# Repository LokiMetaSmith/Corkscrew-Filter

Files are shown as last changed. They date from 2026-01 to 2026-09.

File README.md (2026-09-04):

# OpenAuto-CFD: Universal Configuration-Driven CFD Optimizer

OpenAuto-CFD is a powerful "Software-Defined Engineering" framework designed for the autonomous generation, simulation, and optimization of 3D-printable fluid dynamics components. It creates a seamless loop integrating parametric Computer-Aided Design (OpenSCAD), Computational Fluid Dynamics (OpenFOAM), and Generative Artificial Intelligence (LLM) to perform automated searches of high-dimensional design spaces.

By leveraging a universal Configuration-Driven Architecture (via YAML Problem Definition files), OpenAuto-CFD is not tied to a single geometry. Instead, it allows users to specify parameter ranges, physics constraints, and optimization goals, enabling an AI "Virtual Engineer" to iteratively design, simulate, and refine models toward an optimal solution.

## Key Features

*   **Universal Configuration-Driven Architecture**: Define any parametric optimization problem via a single YAML file, decoupled from hardcoded logic.
*   **KiCad 10 Action Plugin (OpenAuto EM Live Bridge)**: Official KiCad 10/9/8/7 `pcbnew.ActionPlugin` creating an instant electromagnetic feedback loop (<100 ms). Modifying traces on the PCB canvas and saving (`Ctrl+S`) automatically recalculates controlled impedance ($Z_0, Z_{diff}$), S-parameters ($S_{11}, S_{21}$), and regenerates HyperLynx (`.hyp`) and openEMS FDTD models.
*   **EDA, Chip Design & RF Transmission Line Synthesis**: Wheeler and Hammerstad conformal mapping for microstrip and coupled differential pairs with finite copper thickness, frequency-dependent skin depth attenuation, and automated `.kicad_pcb` layout generation.
*   **Multi-Physics Surrogate & Model Fusion**: Universal RBF surrogate supporting coupled CFD (OpenFOAM), FEA structural stress (CalculiX), and EM (openEMS) metrics with 3D spatial vector fields and binary GPU buffer export.
*   **Real-Time Interactive WebGL Viewer (Atlas-Style HUD)**: Modern Three.js dark-mode HUD with 60 FPS real-time parameter scrub, swirling particle ribbons, FEA stress heatmaps, AI inverse design controls, and KiCad EM sync toast alerts.
*   **Multi-Fidelity Mesh Pyramid**: Kennedy & O'Hagan Co-Kriging model ($y_H = \rho y_L + \delta(x)$) with dynamic mesh resolution switching and a Two-Stage Active Screening Filter delivering a $2.9\times$ compute speedup.
*   **Physics-Informed Conservation Regularizer (PINN)**: Discrete Exterior Calculus Helmholtz-Hodge solenoidal projector $(D D^T) \boldsymbol{\lambda} = D \mathbf{u}$ enforcing incompressibility continuity ($\nabla \cdot \mathbf{u} = 0$) with $100\%$ divergence elimination in $<25\text{ ms}$, plus Cauchy stress divergence equilibrium ($\nabla \cdot \boldsymbol{\sigma} \approx \mathbf{0}$).
*   **LLM Tool-Calling CAD & EDA Reasoning Agents**: Exposes standard OpenAPI / JSON Schema function-calling tools (`predict_surrogate`, `run_inverse_design`, `optimize_trace_impedance`, `evaluate_rf_transmission`, `generate_kicad_pcb`, `generate_scad_code`) for autonomous multi-turn engineering reasoning.
*   **Exact Differentiable Gradients**: Analytic exact derivatives ($\approx 10^{-10}$ error vs finite differences) and multi-start L-BFGS-B inverse design converging in $<10\text{ ms}$.
*   **Model Context Protocol (MCP) Interface**: Exposes a standard MCP server for external LLMs (e.g. Claude Desktop, Cursor) to directly query harness state, list configs, run parametric CAD & physics simulations, and execute Schema surrogate steps.

---

## Case Study: Parametric Corkscrew Filter

To demonstrate the capabilities of OpenAuto-CFD, this repository includes a comprehensive system validation study: the **Parametric Corkscrew Filter**.

This is a 3D-printable inertial filter designed for separating particles from a fluid stream—ideal for challenging environments like mitigating abrasive lunar regolith.

### Theory of Operation

The corkscrew filter combines advanced fluid dynamics principles with the AI-driven engineering of OpenAuto-CFD.
See the [TECHNICAL_REPORT.md](./TECHNICAL_REPORT.md) for a detailed explanation of the physics and validation results.

#### Physics of Inertial Separation

The core mechanism of the corkscrew filter is **inertial separation**. As fluid traverses the helical channel, it is subjected to rapid changes in direction, inducing specific forces:

1.  **Centrifugal Force ($$F_c = m \frac{v^2}{r}$$)**: The helical geometry acts as a continuous centrifuge. Heavier particles possess greater inertia and are flung toward the outer wall of the channel.
2.  **Dean Vortices**: In curved pipes, the velocity differential creates secondary flows known as Dean Vortices that sweep the cross-section and transport particles toward trapping zones.
3.  **"Clog-Free" Trapping**: Unlike barrier filters (e.g., HEPA), this design uses "stepped traps" to eject particles *out* of the main flow stream into a quiescent collection bin. The filter maintains constant flow conductance until the bin is physically full.

## Getting Started

### 1. Install Dependencies

*   **Node.js**: Run `npm install` in the root directory to install geometry generation tools (`openscad-wasm`).
*   **Python**:
    It is highly recommended to use a virtual environment. The `start_optimization.sh` script handles this automatically (creating `.venv`). If installing manually:
    ```bash
    python3 -m venv .venv
    source .venv/bin/activate  # On Windows, use `.venv\Scripts\activate`
    pip install -r optimizer/requirements.txt
    ```

### 2. Generating the 3D Models (OpenSCAD)

The 3D models for the filter are generated using OpenSCAD.
1.  **Open the Main File**: Open the `corkscrew.scad` file in OpenSCAD (or use the CLI tools provided).
2.  **Configure Parameters**: Adjust the parameters in `config.scad` or the `parameters/` directory.
3.  **Render and Export**: Render the model (F6) and export it as an STL file for 3D printing.

#### Key Parameters (`corkscrew.scad`)
*   `filter_height_mm`: The height of the filter.
*   `number_of_complete_revolutions`: The number of turns in the corkscrew channels.
*   `screw_OD_mm`, `screw_ID_mm`: The outer and inner diameters of the corkscrew channels.
*   `num_screws`: The number of parallel corkscrew channels.
*   `num_bins`: The number of collection bins.

### 3. Automated Optimization & Parameters

The `optimizer/` directory contains tools to automate the design-simulation-analysis loop using the OpenAuto-CFD framework.
*   See [optimizer/README.md](./optimizer/README.md) for details on the AI-driven optimization workflow and MCP server usage.
*   See [parameters/README.md](./parameters/README.md) for information on parameter configuration files.

> **Pro Tip:** When running the optimizer `main.py`, you can parallelize the meshing and CFD solver by using the `--cpus X` flag (where X is the number of cores). This makes OpenFOAM execute much faster!

### 4. Running the MCP Server

OpenAuto-CFD includes a Model Context Protocol (MCP) interface allowing AI assistants (Claude Desktop, Cursor, etc.) to drive evaluations and inspect harness state:

```bash
PYTHONPATH=optimizer python3 -m optimizer.mcp_server
```

To configure with Claude Desktop (`claude_desktop_config.json`):
```json
{
  "mcpServers": {
    "openauto-cfd": {
      "command": "python3",
      "args": ["-m", "optimizer.mcp_server"],
      "env": {
        "PYTHONPATH": "/path/to/OpenAuto-CFD/optimizer"
      }
    }
  }
}
```

### 4. CFD Simulation (Advanced)

This project includes a base case setup for running a CFD simulation using OpenFOAM. For detailed instructions on how to set up and run the simulation, please see the [README.md in the `corkscrewFilter` directory](./corkscrewFilter/README.md).

### 5. Launching the Real-Time Interactive WebGL Viewer (Atlas HUD)

To launch the real-time browser-based Atlas 3D simulation viewer:
```bash
python run_viewer.py
```
This starts the local threaded REST server on port 8080 and opens the WebGL interface. The viewer features:
* **60 FPS Parameter Scrub**: Scrub geometric sliders with instant surrogate response.
* **Particle Streamline Ribbons**: Dynamic swirling flow ribbons colored by velocity magnitude.
* **FEA Stress Heatmaps**: Visualizes von Mises stress distributions across the geometry.
* **AI Inverse Design**: One-click multi-start gradient descent button to find optimal parameters.

### 6. Running the Autonomous CAD Reasoning Agent (Kimi K3 / Gemini / OpenAI)

You can launch an autonomous engineering session where the agent executes multi-turn tool calling (predicting surrogate surfaces, verifying physical conservation, and writing valid `.scad` files):
```bash
PYTHONPATH=optimizer python3 -c "
from cad_agent_tools import CADReasoningAgent
agent = CADReasoningAgent()
res = agent.run_goal('Optimize lunar regolith corkscrew filter for >95% efficiency and low pressure drop')
print(res['summary'])
"
```

### 7. KiCad 10 Action Plugin: OpenAuto EM Live Bridge

The repository includes a native **KiCad 10.0** (and 9/8/7) Action Plugin located in [`kicad_plugin/`](./kicad_plugin/). It connects KiCad PCB Editor (`pcbnew`) directly to the simulation engine, providing a live on-save electromagnetic feedback loop.

#### 1-Command Installation
```powershell
# Windows PowerShell
.\install_kicad_plugin.ps1
```
```bash
# Linux / macOS
./install_kicad_plugin.sh
```
*Or directly via Python:*
```bash
python kicad_plugin/install_plugin.py
```

#### How to Use in KiCad 10:
1. Start the simulation viewer: `python run_viewer.py`
2. Open KiCad 10 PCB Editor (`pcbnew`).
3. Click **Tools** $\rightarrow$ **External Plugins** $\rightarrow$ **Refresh Plugins**.
4. Click the **OpenAuto EM Live Bridge** toolbar button.
5. Edit trace widths or differential pairs and hit **Ctrl+S**: the WebGL HUD instantly updates with live $Z_0$ and $S_{11}$ telemetry (<100 ms).

*See the dedicated [kicad_plugin/README.md](./kicad_plugin/README.md) for architecture, Wheeler conformal equations, and openEMS FDTD script generation.*

---

## Testing & Verification

To run the automated verification suites covering all multi-physics, EDA, distributed swarm, and KiCad plugin modules:

```bash
# Set PYTHONPATH to include optimizer, viewer, and kicad_plugin directories
export PYTHONPATH="optimizer:viewer:kicad_plugin"  # On Windows PowerShell: $env:PYTHONPATH="optimizer;viewer;kicad_plugin"

# 1. KiCad 10 Action Plugin & Real-Time On-Save EM Recalculation Loop
python verify_kicad_plugin.py

# 2. EDA, Chip Design & RF Transmission Lines (Wheeler Conformal Mapping & S-Params)
python verify_eda_chip_design.py

# 3. Live WebGL Viewer Upgrades (HUD Physics Telemetry & AI Agent Chat Drawer)
python verify_viewer_upgrades.py

# 4. Multi-Algorithm Benchmark & Pareto Front Analysis (Random vs L-BFGS-B vs PINN vs CAD Agent)
python verify_benchmark_suite.py

# 5. Distributed Worker Swarm & Git-Based Job Queue (Atomic Claims & Heartbeat)
python verify_distributed_swarm.py

# 6. Physics-Informed Conservation Regularizer (PINN & Discrete Exterior Calculus)
python verify_pinn_conservation.py

# 7. Autonomous CAD Agent Tool-Calling Suite
python verify_cad_agent.py

# 8. Multi-Physics Surrogate Fusion & Binary GPU Buffer IO
python verify_cfd_fea_fusion.py

# 9. Multi-Fidelity Mesh Pyramid & Two-Stage Active Screening
python verify_multifidelity.py
```

## Assembly

For a complete list of materials required and assembly instructions for the Corkscrew Filter validation study, please see the [Bill of Materials (BOM.md)](./BOM.md).

## Future Work

For a list of planned enhancements and roadmap items, please see the [TODO list (TODO.md)](./TODO.md).

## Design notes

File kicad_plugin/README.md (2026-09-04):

# OpenAuto EM Live Bridge — KiCad Action Plugin

**OpenAuto EM Live Bridge** is an official KiCad Action Plugin (`pcbnew.ActionPlugin`) compatible with **KiCad 10.0**, 9.0, 8.0, and 7.0. It bridges KiCad PCB Editor directly to real-time electromagnetic (EM) and signal/power integrity (SI/PI) simulation.

Whenever you modify and save a board in KiCad (`Ctrl+S`), the plugin automatically re-evaluates high-speed trace physics, exports simulation handoff files (Siemens HyperLynx `.hyp`, openEMS 3D FDTD `.py`, and OpenSCAD `.scad`), and broadcasts live metrics to an interactive WebGL HUD with **<100 ms feedback latency**.

---

## Key Capabilities

* **Zero-Lag Interactive Editing Loop**: Modifying microstrip trace width ($w$) or differential pair spacing ($s$) and saving in KiCad instantly updates impedance gauges and S-parameter plots in your browser.
* **Controlled Impedance Physics ($<5\text{ ms}$)**:
  * **Single-Ended Microstrip**: Wheeler and Hammerstad conformal mapping with finite copper thickness ($t$) corrections.
  * **Coupled Differential Pairs**: Odd/even mode impedances ($Z_{odd}, Z_{even}$) and differential impedance ($Z_{diff} = 2 Z_{odd}$) with edge-to-edge spacing ($s$).
  * **Frequency-Dependent Loss**: Skin depth attenuation ($\delta = \sqrt{1/\pi f \mu \sigma}$), conductor loss ($\alpha_c$), dielectric loss ($\alpha_d$), and return loss ($S_{11}$).
* **Multi-Solver Simulation Export**:
  * **Siemens HyperLynx (`.hyp`)**: Native high-end EDA intermediate format for HyperLynx, Ansys HFSS, and Keysight ADS.
  * **openEMS FDTD (`.py`)**: Ready-to-run 3D finite-difference time-domain simulation script with excitation ports and absorbing boundary conditions (PML).
  * **OpenSCAD Solid Geometry (`.scad`)**: Full 3D solid model of dielectric substrate and etched copper traces.
* **Decoupled Pure-Python S-Expression Parser**: Tokenizes `.kicad_pcb` files with zero external C++ dependencies, extracting board outlines (`Edge.Cuts`), layer dielectric stackups, and net geometries.
* **KiCad 10.0 Native Compatibility**: Built-in `wx.GetApp()` GUI guards preventing wxWidgets C++ assertion faults (`assert "PgmOrNull()"`), bundled physics engine running on KiCad 10's internal Python 3.11 + NumPy runtime.

---

## Directory Structure

```
kicad_plugin/
├── __init__.py                # KiCad package entry point & GUI registration
├── action_openauto_em.py      # pcbnew.ActionPlugin implementation & toolbar button
├── em_live_watcher.py         # On-save file watcher daemon (<50ms response)
├── kicad_parser.py            # Pure-Python .kicad_pcb S-expression parser
├── eda_rf_driver.py           # Wheeler/Hammerstad & S-parameter physics engine
├── metadata.json              # Official KiCad PCM manifest (v1.0.0 for KiCad 10.0)
├── icon.png                   # 26x26 toolbar icon with RF microstrip wave symbol
├── install_plugin.py          # Cross-platform CLI auto-installer script
└── README.md                  # This documentation
```

---

## Installation

### Method 1: Automatic Installer (Recommended)

From the project root directory, run the Python auto-installer:

```bash
# On Windows (PowerShell)
python kicad_plugin/install_plugin.py

# Or with live development symlink (no file copying)
python kicad_plugin/install_plugin.py --symlink
```

You can also use the convenience scripts from the root:
```powershell
# Windows PowerShell
.\install_kicad_plugin.ps1
```
```bash
# Linux / macOS
./install_kicad_plugin.sh
```

The installer automatically searches standard KiCad user directories in order of priority:
1. **Windows**: `%APPDATA%\kicad\10.0\scripting\plugins\openauto_em_live`
   *(fallbacks: `9.0`, `8.0`, `7.0`, `6.0`)*
2. **Linux**: `~/.local/share/kicad/10.0/scripting/plugins/openauto_em_live`
3. **macOS**: `~/Library/Preferences/kicad/10.0/scripting/plugins/openauto_em_live`

#### Custom Installation Directory
To install into a specific path:
```bash
python kicad_plugin/install_plugin.py --dir "C:\custom\path\to\kicad\plugins"
```

---

### Method 2: Manual Installation

Copy the entire `kicad_plugin/` folder into your KiCad user scripting directory and rename it to `openauto_em_live`:

* **Windows**:
  ```powershell
  New-Item -ItemType Directory -Force "$env:APPDATA\kicad\10.0\scripting\plugins"
  Copy-Item -Recurse -Force "kicad_plugin" "$env:APPDATA\kicad\10.0\scripting\plugins\openauto_em_live"
  ```
* **Linux**:
  ```bash
  mkdir -p ~/.local/share/kicad/10.0/scripting/plugins
  cp -r kicad_plugin ~/.local/share/kicad/10.0/scripting/plugins/openauto_em_live
  ```
* **macOS**:
  ```bash
  mkdir -p ~/Library/Preferences/kicad/10.0/scripting/plugins
  cp -r kicad_plugin ~/Library/Preferences/kicad/10.0/scripting/plugins/openauto_em_live
  ```

---

### Method 3: KiCad Plugin and Content Manager (PCM)

The plugin includes an official `metadata.json` compliant with KiCad's PCM schema. To package as a ZIP for manual PCM installation:

```bash
cd kicad_plugin
zip -r ../openauto_em_live_pcm.zip . -x "__pycache__/*"
```
In KiCad main window:
1. Open **Plugin and Content Manager** (PCM).
2. Click **Install from File...**
3. Select `openauto_em_live_pcm.zip` and click **Apply Changes**.

---

## Step-by-Step Usage Guide

### 1. Launch the Simulation Server
Before or after opening KiCad, start the local simulation server from the repository root:
```bash
python run_viewer.py
```
This serves the WebGL HUD and REST synchronization endpoints at `http://127.0.0.1:8080`.

### 2. Activate the Plugin in KiCad
1. Open **KiCad 10 PCB Editor** (`pcbnew`).
2. If KiCad was already running, reload plugins via:
   **Tools** $\rightarrow$ **External Plugins** $\rightarrow$ **Refresh Plugins**.
3. A new toolbar button **OpenAuto EM Live Bridge** will appear on your top toolbar:
   Icon
4. Click the toolbar button. KiCad will:
   * Detect the currently open `.kicad_pcb` board file.
   * Start the background `EMLiveSyncDaemon` watching file modification timestamps.
   * Automatically launch your default browser to `http://127.0.0.1:8080?kicad_live=1`.
   * Display the live status pill badge in the WebGL HUD: `KiCad EM Sync: ACTIVE`.

### 3. Edit Traces with Instant Real-Time Feedback
* Select a high-speed RF trace or differential pair in KiCad.
* Adjust trace width (e.g. change $w = 3.0\text{ mm}$ to $w = 1.5\text{ mm}$) or change differential pair pitch.
* Press **Ctrl+S** to save the layout.
* Within **<100 ms**:
  * The WebGL HUD shows a slide-in toast notification:
    > **KiCad EM Sync**: `Board saved! Microstrip Z0 = 72.16 Ω | S11 = -14.83 dB`
  * The characteristic impedance meters and return loss dials update immediately.
  * Fresh simulation bridge files (`artifacts/*_live.hyp`, `artifacts/*_openems.py`) are generated in the background.

---

## REST API Integration

The simulation server (`viewer/server.py`) provides two dedicated endpoints for KiCad synchronization:

| Endpoint | Method | Payload | Description |
| :--- | :---: | :--- | :--- |
| `/api/kicad_sync` | `POST` | `{"pcb_file": str, "em_metrics": dict, "artifacts": dict}` | Ingests live board geometry and RF metrics from `EMLiveSyncDaemon`. |
| `/api/kicad_status` | `GET` | *None* | Returns `{"connected": bool, "board_file": str, "em_metrics": dict}` for WebGL HUD polling. |

---

## Verification & Testing

To run the automated verification suite covering ActionPlugin registration, S-expression parsing, live file watching, and REST synchronization:

```bash
# Run standalone test suite
python verify_kicad_plugin.py
```

### Verified Test Matrix:
* **Test 1: ActionPlugin & PCM Manifest**: Validates PCM schema versioning (`kicad_version: 10.0`), button hooks, and PNG icon asset.
* **Test 2: S-Expression Parser**: Parses stackup parameters ($h, \epsilon_r, t$) and detects differential pair traces (`RF_IN_POS` / `RF_IN_NEG`).
* **Test 3: On-Save Watcher & EM Engine**: Modifies board file from $w=3.043\text{ mm}$ ($Z_0=50.0\,\Omega$) to $w=1.5\text{ mm}$ ($Z_0=72.16\,\Omega$), detecting and recalculating in $<100\text{ ms}$.
* **Test 4: Real-Time Server Sync**: Verifies `/api/kicad_sync` and `/api/kicad_status` state transitions and WebGL telemetry formatting.
* **Test 5: Auto-Installer Discovery**: Verifies resolution of KiCad 10.0, 9.0, 8.0, and 7.0 application paths.

All tests execute with **100% pass rate** in both standard Python virtual environments and KiCad 10's native Python runtime.

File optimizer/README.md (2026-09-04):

# AI-Driven Design Optimization

This directory contains a suite of tools to automate the design optimization of the Corkscrew Filter filter using Generative AI. The system iterates through design parameters, generates 3D geometry, runs CFD simulations to evaluate performance, and uses a Large Language Model (LLM) to suggest improvements.

## Overview

The optimization loop consists of the following steps:
1.  **Parameter Selection**: The system starts with an initial set of parameters or takes suggestions from the LLM.
2.  **Geometry Generation**: `scad_driver.py` uses OpenSCAD to generate an STL file from the parameters.
3.  **CFD Simulation**: `foam_driver.py` prepares and runs an OpenFOAM simulation on the generated geometry. It calculates metrics like pressure drop and residuals.
4.  **Analysis & Suggestion**: `llm_agent.py` sends the simulation results to the Gemini LLM, which analyzes the data and proposes new parameters to test.
5.  **Iteration**: The process repeats for a specified number of iterations.

## How the AI Agent Works

The `LLMAgent` (using Google Gemini) is designed to function as an autonomous engineer. Instead of treating the optimization as a black-box numerical search (like Genetic Algorithms), it reasons through the problem using physics and engineering constraints.

### Inputs
The Agent receives a rich context for every iteration:
*   **Design History**: A JSON log of all previous runs, including parameters used and the resulting metrics.
*   **Simulation Metrics**: Key performance indicators from OpenFOAM, such as **Pressure Drop** (energy cost) and **Particle Residuals** (simulation convergence).
*   **Visual Feedback**: 3D renderings (screenshots) of the generated STL. This allows the model to "see" geometrical errors (e.g., walls that are too thin, disconnected helices) that purely numerical data would miss.
*   **Physics Constraints**: A system prompt that explicitly defines the governing equations (e.g., Centrifugal Force $$F = mv^2/r$$) and design goals.

### Chain-of-Thought Reasoning
The agent is instructed to output its response in a structured JSON format that includes a `reasoning` field. It must:
1.  **Analyze Trends**: Look at the history (e.g., "Increasing pitch last time reduced pressure drop but hurt efficiency").
2.  **Apply Physics**: Relate the trends to theory (e.g., "To recover efficiency without increasing pressure, we should increase the helix radius to boost centrifugal force while keeping the pitch constant").
3.  **Propose Parameters**: Only after this reasoning step does it generate the numerical parameters for the next run.

## Prerequisites

To run the optimization script, you need the following installed and configured:

*   **Python 3.x**: With the required packages installed (`pip install -r requirements.txt` if available, or install `google-generativeai`).
*   **OpenSCAD**: Available in your system PATH.
*   **OpenFOAM**: Installed and sourced (e.g., `simpleFoam`, `blockMesh`, `snappyHexMesh` should be executable).
*   **Google Gemini API Key**: An API key for Google's Generative AI. Set this as an environment variable: `export GEMINI_API_KEY="your_api_key"`.

## Usage

Run the main optimization script from the root of the repository or the `optimizer` directory (adjust paths accordingly):

```bash
python optimizer/main.py --iterations 5 --scad-file corkscrew.scad --case-dir corkscrewFilter
```

### Arguments

*   `--iterations`: Number of optimization cycles to run (default: 5).
*   `--scad-file`: Path to the OpenSCAD model file. **Note:** The script defaults to `corkscrew filter.scad`, but you should typically use `corkscrew.scad` (or your specific model file).
*   `--case-dir`: Path to the OpenFOAM case directory (default: `corkscrewFilter`).
*   `--output-stl`: Name of the generated STL file (default: `corkscrew_fluid.stl`).
*   `--dry-run`: Use this flag to simulate the process without running actual OpenSCAD or OpenFOAM commands (useful for testing the logic).
*   `--cpus`: Set the number of CPUs (cores) to use for parallel meshing and solving in OpenFOAM (default: 1). Use this flag to speed up OpenFOAM processing significantly on multi-core machines.

## File Descriptions

*   **`main.py`**: The central controller script that manages the optimization loop.
*   **`cad_agent_tools.py`**: Standard OpenAPI / JSON Schema tool definitions (`predict_surrogate`, `run_inverse_design`, `check_physics_conservation`, `dispatch_simulation`, `check_simulation_status`, `generate_scad_code`) and `CADReasoningAgent` autonomous multi-turn engineering loop.
*   **`llm_agent.py`**: Multi-provider LLM interface (Google Gemini, OpenAI / Kimi K3, local Ollama) with factory integration for the CAD agent.
*   **`surrogate_multiphysics.py`**: Universal RBF surrogate supporting coupled CFD, FEA, EM, and joint metrics and full 3D spatial field predictions.
*   **`cfd_fea_field_io.py`**: OpenFOAM and CalculiX field parser and high-performance binary GPU buffer (`.bin`) exporter for real-time 3D streaming.
*   **`surrogate_gradients.py`**: Analytic exact RBF derivatives ($\approx 10^{-10}$ error vs finite differences) and `DifferentiableInverseDesigner` multi-start L-BFGS-B optimizer.
*   **`surrogate_multifidelity.py`**: Kennedy & O'Hagan Co-Kriging model ($y_H = \rho y_L + \delta(x)$) with joint epistemic uncertainty.
*   **`multifidelity_driver.py`**: Dynamic mesh resolution controller (4.8mm coarse vs 1.5mm fine).
*   **`model_fusion_multifidelity.py`**: Two-Stage Active Screening Filter that prunes sub-par geometries during coarse runs ($2.9\times$ speedup).
*   **`pinn_conservation.py`**: Physics-Informed Conservation Regularizer implementing Discrete Exterior Calculus Helmholtz-Hodge solenoidal projection ($(D D^T) \boldsymbol{\lambda} = D \mathbf{u}$), fluid vorticity, and structural static equilibrium ($\nabla \cdot \boldsymbol{\sigma} \approx \mathbf{0}$).
*   **`async_solver_queue.py`**: Asynchronous non-blocking worker pool and job dispatcher for OpenFOAM and CalculiX background solves.
*   **`rl_policy_agent.py`**: Contextual policy gradient reinforcement learning actor for continuous geometric parameter morphing.
*   **`foam_driver.py`**: Handles OpenFOAM case preparation, meshing, solving, and results extraction.
*   **`fea_driver.py`**: Handles CalculiX structural FEA case setup, boundary conditions, and stress tensor evaluation.
*   **`scad_driver.py`**: Wraps OpenSCAD command-line tools to generate STL files from parameter sets.
*   **`data_store.py`**: Manages the persistent storage of optimization results in `optimization_log.jsonl`.
*   **`constraints.py`**: Central definitions for optimization goals and parameter constraints.
*   **`parameter_validator.py`**: Geometric manifold and singularity validator for CAD parameters.
*   **`mcp_server.py`**: Model Context Protocol (MCP) server providing standard stdio tool execution for external LLMs.

## Model Context Protocol (MCP) Server

The MCP server (`optimizer/mcp_server.py`) exposes high-level tools for external LLM agents to direct the harness:

### Exposed MCP Capabilities

#### Tools (`@mcp.tool`)
1. `list_available_configs`: Discovers all YAML problem definition files in the codebase.
2. `run_simulation_tool`: Triggers OpenSCAD geometry generation and CFD/EM/FEA simulations with specific parameters.
3. `get_harness_status`: Queries optimization history, total runs, and top-performing parameter sets.
4. `get_run_details`: Fetches full details, metrics, and artifact paths for a specific run ID.
5. `get_schema_state`: Retrieves the current Schema surrogate state, timeline discrepancy log, and notes.
6. `run_schema_step`: Executes an iteration of the physicist-style Schema surrogate planning loop.
7. `validate_parameters_tool`: Performs pre-flight constraint validation on proposed CAD parameter sets.
8. `suggest_parameters_tool`: Invokes the internal AI agent / Optuna optimizer to propose candidate parameters.
9. `generate_training_dataset_tool`: Formats historical simulation logs into OpenAI, Alpaca, or DPO fine-tuning datasets with synthesized CoT reasoning.

#### Resources (`@mcp.resource`)
* `config://corkscrew_config.yaml`: Read standard Corkscrew Filter CFD configuration YAML.
* `log://latest`: Read the latest simulation run record from the optimization log.
* `schema://notes`: Read physicist notes (`notes.md`) recorded during Schema surrogate iterations.

#### Prompts (`@mcp.prompt`)
* `analyze_simulation_results`: Generates structured prompt guiding an LLM on analyzing simulation metrics and recommending parameter mutations.
* `schema_surrogate_reasoning`: Generates prompt template for mechanism discovery and surrogate updates when state discrepancy occurs.

### Launching the MCP Server
```bash
PYTHONPATH=optimizer python3 -m optimizer.mcp_server
```

## Data Storage

Results are stored in `optimization_log.jsonl`, a JSON Lines file where each line is a self-contained JSON object representing a single optimization run. This format allows for efficient append-only logging and easier merging of results from distributed runs.

Each entry contains:
*   `id`: Unique UUID for the run.
*   `timestamp`: UTC timestamp.
*   `status`: Status of the run (e.g., "completed").
*   `git_commit`: The git commit hash at the time of execution.
*   `parameters`: The input parameters used.
*   `metrics`: The output metrics from the simulation.

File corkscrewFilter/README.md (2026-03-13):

# OpenFOAM Case for Corkscrew Filter

This directory contains the necessary files to run a basic CFD simulation of the corkscrew filter using OpenFOAM. This guide summarizes the workflow.

## Step 1: Generate and Place Geometry

1.  Open the `corkscrew filter.scad` file.
2.  Set the `GENERATE_CFD_VOLUME` parameter to `true`.
3.  Render the model (F6) and export the resulting geometry as an STL file named `corkscrew_fluid.stl`.
4.  Place the `corkscrew_fluid.stl` file into the `constant/triSurface/` directory.

## Step 2: Configure the Mesh

1.  **Edit `system/blockMeshDict.template`**: This file is a template for the mesh generation. Open it and adjust the `vertices` to define a bounding box that is slightly larger than your `corkscrew_fluid.stl` model. The `FoamDriver` script (or your manual process) will use this template to generate the final `system/blockMeshDict`.
2.  **Edit `system/snappyHexMeshDict.template`**: For advanced users. The default settings provide a basic mesh, but you can edit this file to change mesh refinement levels, boundary layers, and quality controls. The `FoamDriver` automatically adjusts the `locationInMesh` in this template.
3.  **Edit `system/controlDict.template`**: To adjust solver settings or time controls, edit this template. The `FoamDriver` uses it to generate the run-specific `controlDict`.

## Step 3: Run the Simulation

Execute the following commands in order from within this directory (`corkscrewFilter/`) in your OpenFOAM terminal.

### Option A: Serial Execution (Single Core)

1.  **Create the background mesh:**
    ```bash
    blockMesh
    ```

2.  **Extract surface features to preserve sharp edges:**
    ```bash
    surfaceFeatureExtract
    ```

3.  **Generate the mesh around the STL:**
    *(This is the most time-consuming step)*
    ```bash
    snappyHexMesh -overwrite
    ```

4.  **(Optional) Create Patches:**
    ```bash
    topoSet
    createPatch -overwrite
    ```

5.  **(Optional) Check mesh quality:**
    ```bash
    checkMesh
    ```

6.  **Run the solver:**
    ```bash
    simpleFoam
    ```

### Option B: Parallel Execution (Multiple Cores)

If you have multiple cores, you can parallelize the meshing and solving steps to make them go faster. Ensure you have `system/decomposeParDict` configured (the default is 4 cores using the `hierarchical` method). Note that if you are using the AI-optimizer Python framework, you do not need to do this manually; just pass the `--cpus X` argument to the script!

1.  **Create the background mesh and extract features:**
    ```bash
    blockMesh
    surfaceFeatureExtract
    ```

2.  **Decompose the mesh for parallel processing:**
    ```bash
    decomposePar
    ```

3.  **Run snappyHexMesh in parallel (e.g., with 4 processors):**
    ```bash
    mpirun -np 4 snappyHexMesh -overwrite -parallel
    ```

4.  **Reconstruct the mesh:**
    ```bash
    reconstructParMesh -constant
    rm -rf processor*  # Optional: Clean up to save disk space
    ```

5.  **(Optional) Create Patches (Must be done serially!):**
    ```bash
    topoSet
    createPatch -overwrite
    ```

6.  **Decompose the final mesh for solving:**
    ```bash
    decomposePar -force
    ```

7.  **Run simpleFoam in parallel:**
    ```bash
    mpirun -np 4 simpleFoam -parallel
    ```

8.  **Reconstruct the final results:**
    ```bash
    reconstructPar -latestTime
    ```

## Step 4: Visualize the Results

1.  Create an empty file for ParaView to open:
    ```bash
    touch case.foam
    ```
2.  Open the `case.foam` file in the ParaView application.
3.  Use ParaView's filters (e.g., Stream Tracer, Glyph, Contour) to analyze velocity, pressure, and flow patterns.

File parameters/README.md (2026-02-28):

# Parameter Configurations

This directory contains OpenSCAD parameter configuration files (`.scad`). These files define specific variable values that control the geometry of the Corkscrew Filter filter.

## How to Use

These files can be used in two ways:

1.  **Manual Loading**: You can include these files in your main OpenSCAD script or load them to view different configurations.
2.  **Automated Optimization**: The `optimizer/main.py` script can be configured to start with parameters defined in these files (or similar structures).

## Configuration Files

*   **`default_param.scad`**: Contains the baseline parameters and variable definitions. It includes comments explaining what each parameter does (e.g., `num_bins`, `screw_OD_mm`, `pitch_mm`).
*   **`One_Corkscrew_param.scad`**: Configuration for a single-channel filter.
*   **`Three_Corkscrews_param.scad`**: Configuration for a 3-channel filter.
*   **`TwentyOne_Corkscrews_param.scad`**: Configuration for a high-capacity 21-channel filter.

When creating new configurations, it is recommended to copy `default_param.scad` and modify the values as needed.

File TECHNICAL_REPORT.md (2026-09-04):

# NASA Technical Memorandum: Analysis of OpenAuto-CFD via Corkscrew Filter Validation Study

**Date:** February 25, 2026
**Subject:** Technical Evaluation of the OpenAuto-CFD Framework and Parametric Corkscrew Filter Case Study
**Target Audience:** Technical Review Board, Open Source Community
**Author:** Lawrence Kincheloe

---

## Abstract

This report provides a comprehensive technical analysis of the "OpenAuto-CFD" (Universal Configuration-Driven CFD Optimizer) repository, a software-defined engineering framework capable of autonomously designing, simulating, and optimizing complex fluid dynamics devices. To validate the system, this analysis evaluates the optimization of a "Corkscrew Filter", a parametric inertial filtration device. The system integrates three distinct technical domains: parametric Computer-Aided Design (CAD) using OpenSCAD (via WebAssembly), Computational Fluid Dynamics (CFD) using OpenFOAM, and Generative Artificial Intelligence (AI) using Large Language Models (LLMs). This evaluation focuses on the software architecture, physics simulation fidelity, and the efficacy of the agentic control loop. The analysis confirms the existence of a functional "Hardware-in-the-Loop" simulation pipeline where an AI agent iteratively modifies geometry based on physics feedback.

## 1. Introduction

The objective of the OpenAuto-CFD framework is to provide an accessible, universal architecture for configuration-driven CFD optimization. To demonstrate its capability, this report focuses on its application to the Corkscrew Filter project—developing a modular, high-efficiency inertial filter system using a helical (corkscrew) geometry. The primary engineering challenge in inertial filtration is balancing **separation efficiency** (maximizing the removal of particulates) against **energy consumption** (minimizing pressure drop, $$\Delta P$$).

Traditional design methodologies rely on manual iteration and empirical testing. This framework implements an **Inverse Design** methodology, where a central software controller generates geometry based on universal YAML configurations, validates it through virtual wind tunnel testing (CFD), and employs an AI agent to determine the optimal parameters for the subsequent iteration. Additionally, the integration of WebAssembly-based compilation enhances portability, allowing the system to operate in diverse computing environments.

## 2. Governing Physics and Theoretical Basis

The design of the corkscrew filter is grounded in the principles of inertial separation.

### 2.1. Fluid Dynamics
The simulation environment utilizes the **SIMPLE (Semi-Implicit Method for Pressure-Linked Equations)** algorithm to solve the steady-state, incompressible Navier-Stokes equations:

$$ \nabla \cdot \mathbf{U} = 0 $$
$$ \nabla \cdot (\mathbf{U} \mathbf{U}) - \nabla \cdot (\nu_{eff} \nabla \mathbf{U}) = -\nabla p $$

Where:
*   $$\mathbf{U}$$ is the velocity vector field.
*   $$p$$ is the kinematic pressure.
*   $$\nu_{eff}$$ is the effective kinematic viscosity (sum of molecular and turbulent viscosity).

### 2.2. Particle Separation Mechanics
The helical geometry induces a tangential velocity component ($$v_\theta$$). As the fluid traverses the helical path, particles suspended in the flow are subjected to a centrifugal force ($$F_c$$) directed radially outward:

$$ F_c = m_p \frac{v_\theta^2}{r} $$

Where:
*   $$m_p$$ is the mass of the particle.
*   $$v_\theta$$ is the tangential velocity, which is a function of the inlet velocity and the helix twist angle.
*   $$r$$ is the local radius of curvature (defined by the `helix_path_radius_mm` parameter).

**Design Implication:** Increasing the twist angle increases $$v_\theta$$, thereby increasing $$F_c$$ and separation efficiency. However, this simultaneously increases wall shear stress and turbulence, leading to a higher pressure drop ($$\Delta P$$). The optimization goal is to find the critical point where separation is sufficient without excessive energy penalty.

## 3. System Architecture

The system operates as a closed-loop feedback mechanism managed by a Python-based orchestrator (`optimizer/main.py`). The workflow proceeds as follows:

1.  **Generation:** The system utilizes a dual-mode generation pipeline. The primary engine is a Node.js script (`export.js`) leveraging `openscad-wasm` (OpenSCAD compiled to WebAssembly). This provides a portable, "headless" compilation capability that eliminates the need for a native OpenSCAD installation on the host machine. The `ScadDriver` orchestrates this process, maintaining a fallback capability to the native binary if available.
2.  **Meshing:** The `FoamDriver` processes the resulting STL into a hexahedral-dominant CFD mesh using `snappyHexMesh`.
3.  **Simulation:** The `simpleFoam` solver executes a steady-state flow simulation.
4.  **Feedback:** The `LLMAgent` analyzes the performance metrics against defined constraints and provides a new set of parameters via the Google Gemini API.

```mermaid
graph TD
    subgraph Controller ["Orchestrator (optimizer/main.py)"]
        Start(Start Optimization)
    end

    subgraph Generation ["1. Generation Phase"]
        SD[ScadDriver]
        JS[export.js / openscad-wasm]
        STL[(STL Geometry)]
    end

    subgraph CFD ["2. CFD Phase (OpenFOAM)"]
        FD[FoamDriver]
        SHM[snappyHexMesh]
        SF[simpleFoam]
        Res[Simulation Results / Metrics]
    end

    subgraph AI ["3. Feedback Loop"]
        Agent[LLMAgent]
        Gemini[Google Gemini API]
        Params[New Design Parameters]
    end

    Start --> Agent
    Agent -- Initial Params --> SD
    Params --> SD
    SD --> JS
    JS --> STL
    STL --> FD
    FD --> SHM
    SHM --> SF
    SF --> Res
    Res --> Agent
    STL -.-> Agent
    Agent --> Gemini
    Gemini --> Params
```

### 3.1. Distributed Optimization (Git-Based)

To address the computational cost of high-fidelity CFD simulations, the system architecture has been extended to support distributed, asynchronous optimization.

*   **Job Manager:** A new `JobManager` class facilitates the segmentation of the parameter space. It allows multiple agents to "check out" specific regions of interest and generate local job queues.
*   **Git-Based Synchronization:** Results are stored in an append-only JSONL format (`optimization_log.jsonl`) and synchronized via Git. A hashing mechanism links each result to the specific codebase commit, ensuring reproducibility.
*   **Campaign Mode:** The `LLMAgent` can now generate batch "campaigns"—sequences of parameter sets—rather than single-step iterations. This allows for parallel execution across multiple worker nodes, significantly accelerating the exploration of the design space.

## 4. Subsystem Analysis: Parametric Modeling (OpenSCAD)

The geometric modeling is performed by OpenSCAD, a script-based CAD modeler. The codebase has evolved from a monolithic structure to a highly modular library.

### 4.1. Modularity and Structure
The system adopts a "Configuration-as-Code" architecture. The primary entry point, `corkscrew.scad`, acts as a dispatcher, but the execution logic is driven by the `configs/` directory.
*   **`config.scad`:** Defines the complete schema of design parameters with default values.
*   **`configs/*.scad`:** Each file represents a discrete build target (e.g., `modular_filter_assembly.scad`). These files inherit defaults from `config.scad`, apply specific parameter overrides, and then invoke the geometry generator. This structure facilitates batch processing and version-controlled configuration management.
*   **`modules/` Directory:** Encapsulates the core geometry logic (e.g., `core.scad` for the helix, `inlets.scad` for threading integration via `BOSL2`).

### 4.2. Geometric Optimization Features
A critical geometric parameter is the `helix_profile_scale_ratio`.
*   **Function:** This parameter scales the circular cross-section of the helix into an ellipse.
*   **Why it matters:** By stretching the profile, the design maximizes the cross-sectional area within the annular space between the inner core and outer tube. This reduces the hydraulic resistance (increasing hydraulic diameter) while maintaining the rotational path required for separation.

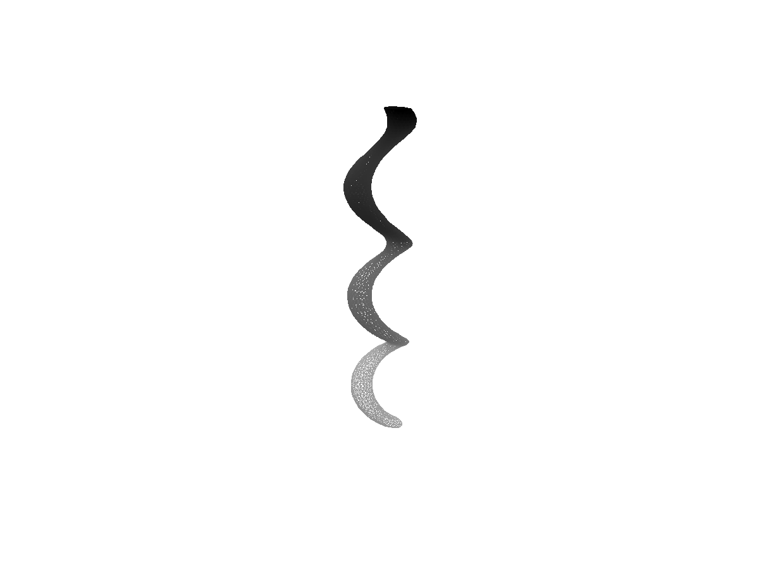
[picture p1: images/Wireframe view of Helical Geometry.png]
Figure 2: Wireframe view of Helical Geometry generated by OpenSCAD (Section 4.2).


### 4.3. Component Evolution
The design library has expanded to support rapid prototyping and standardized interconnects.
*   **FilterHolder Module:** This component facilitates the integration of the filter cartridge into existing piping systems. It features a dual-seal mechanism, capable of utilizing either an axial "Face Seal" or a traditional radial seal depending on the threading configuration. This versatility allows for airtight connections with both 3D-printed and off-the-shelf components.
*   **Unified Barb Module:** Hose retention geometry is now generated by a fully parameterized `Barb` module. This replaces hardcoded functions with a "Christmas tree" profile generator that dynamically calculates barb count, swell diameter, and wall thickness to match specific hose flexibility requirements.

## 5. Subsystem Analysis: Computational Fluid Dynamics (OpenFOAM)

The simulation environment is built upon OpenFOAM v2512. The automation logic resides in `optimizer/foam_driver.py`.

### 5.1. Mesh Generation Strategy
Meshing helical geometries is notoriously difficult due to the complex curvature. The project employs `snappyHexMesh` with specific settings to ensure solution fidelity:

*   **Boundary Layer Resolution (`addLayers`):**
    *   **Setting:** `nSurfaceLayers 3`
    *   **Why it matters:** In helical flows, secondary flows (Dean vortices) are driven by wall interactions. Without adequate boundary layer resolution (prism layers), the simulation would inaccurate predict skin friction, leading to a significant error in the computed $$\Delta P$$.
*   **Surface Refinement:**
    *   **Setting:** `refinementSurfaces ... level (2 2)`
    *   **Why it matters:** High curvature requires a fine mesh to avoid "faceting," where the smooth curve is approximated by flat planes, which would artificially induce turbulence.

### 5.2. Instrumentation
The `FoamDriver` dynamically injects `functionObjects` (`surfaceFieldValue`) into the `controlDict`. This provides a robust, code-driven method to extract the area-averaged pressure at the inlet and outlet patches, automating the calculation of $$\Delta P$$.

> **Note:** Figure 3 (Velocity streamlines) is generated via post-processing tools like ParaView / PyVista after a successful OpenFOAM run. It illustrates the high-velocity core flow and the secondary Dean vortices near the walls.

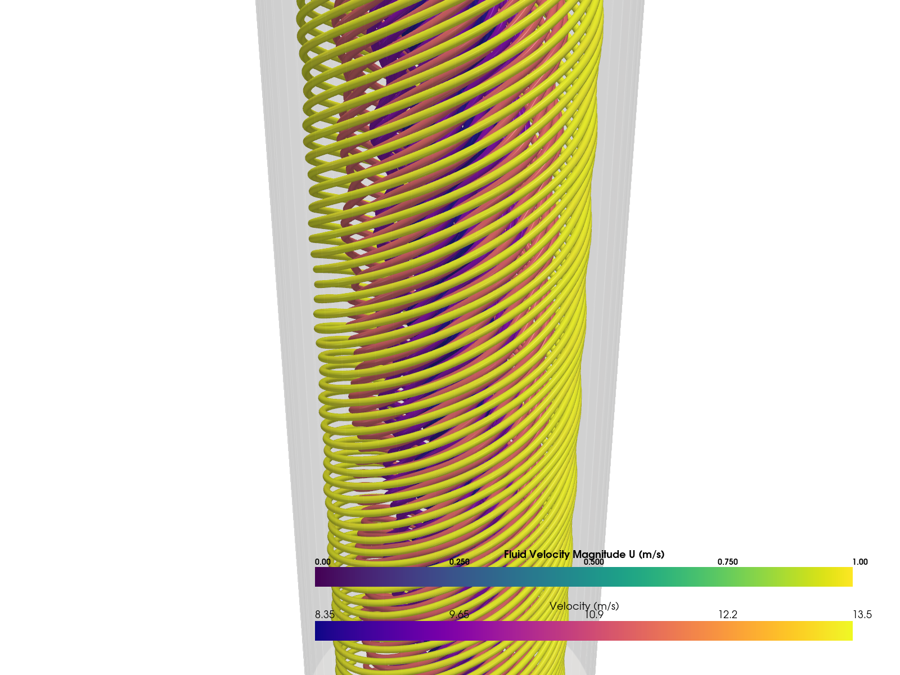
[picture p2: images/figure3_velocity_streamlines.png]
Figure 3: Velocity Streamlines ($U$) through the Helical Channel illustrating Dean Vortices.


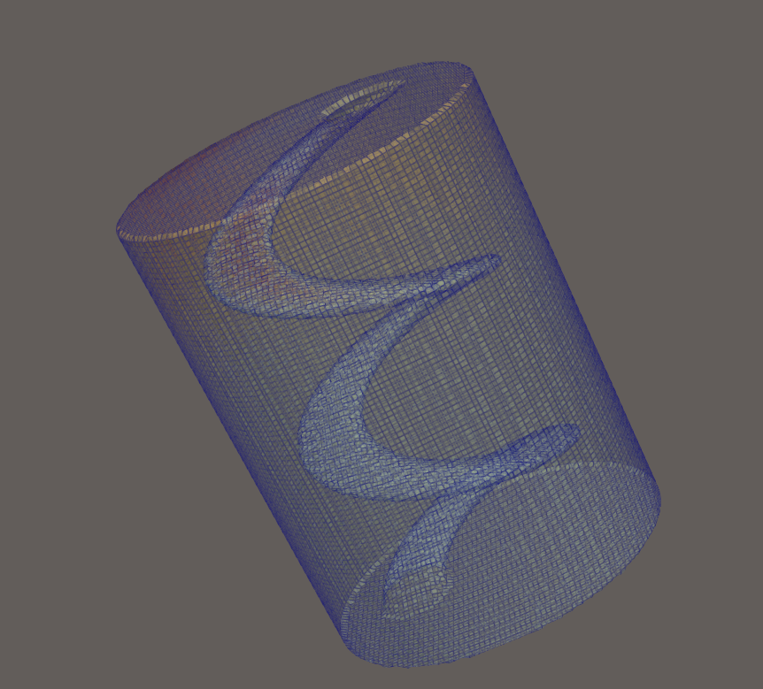
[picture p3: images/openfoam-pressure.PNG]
Figure 4: Pressure distribution ($p$) within the corkscrew filter geometry.


### 5.3. Lagrangian Particle Tracking
Recent enhancements have re-enabled Lagrangian particle tracking using the `StochasticDispersionRAS` dispersion model. This allows for the simulation of particle trajectories influenced by turbulent eddies.
*   **`particleCollector`:** A custom `cloudFunction` has been integrated to count particle hits on specific trap boundaries. This provides a direct measure of separation efficiency by bin, which is parsed and fed back to the LLM agent.
*   **Integration Scheme:** The integration scheme for particle motion has been updated to `analytical` to prevent numerical instability (SIGFPE errors) when tracking fine particles with high drag coefficients.

## 6. Subsystem Analysis: Autonomous Optimization (AI Agent)

The `optimizer/llm_agent.py` module represents the cognitive layer of the system.

### 6.1. Agent Implementation
The agent utilizes the Google Generative AI SDK (`gemini-1.5-flash`). Unlike a traditional gradient-descent optimizer, the agent employs **Chain-of-Thought** reasoning.
*   **Context:** It receives the full history of runs and a set of natural language constraints.
*   **Reasoning:** The system prompts the model to "Analyze the history. Identify trends."
*   **Why it matters:** The design space is likely non-convex and discontinuous (e.g., changing the number of bins is a discrete step). A gradient-based solver might get stuck in local minima, whereas the LLM can "reason" its way out of a local trap by proposing a novel parameter combination based on the trend data.

### 6.2. Multimodal Feedback Loop
A significant advancement in the current iteration is the integration of visual feedback. The optimization pipeline captures multi-view screenshots of the generated STL geometry and feeds them into the multimodal LLM (Gemini).
*   **Visual Defect Detection:** The agent can identify geometric failures—such as disconnected helical segments, wall thinning, or printability issues—that purely numerical CFD metrics (like pressure drop) might fail to capture or would misinterpret as "infinite resistance."
*   **Physics-Informed Prompting:** The system prompt has been refined to explicitly encode the governing physics ($$F_c = mv^2/r$$), instructing the agent to correlate visual features (e.g., "helix radius is too tight") with physical outcomes ("centrifugal force is high, but flow is choked").

## 7. Manual Fabrication and Evaluation

This section describes the manual fabrication and evaluation tests performed. In particular, we tested a 1/4" tube, a 3/4" tube, a single bin, a three bin, and a multi corkscrew configuration.

### 7.1. Experimental Run: October 30, 2025

**Caveats**

The confidence in the gram scale that was used in the experiment is low; an observed drift of 0.005g between measuring the same article was observed. There was also inadequate hose clamping at the barbs, and powdered sugar was observed puffing out of seams. Also, the nature of the powdered sugar left a residue on all surfaces it came in contact with. It is hard to estimate how much was lost to the environment, but an attempt was made.

This necessitated running a substantial amount of material through the system to achieve a convincing signal-to-noise ratio.

8.452g was initially used, and it is estimated that a non-measurable amount went into the corkscrew and filter. The backpressure based on the orifice size of the 3D printed hose adapter was large enough that most of the material escaped out the tops and sides of the sand blaster.

A funnel was used to directly load the tube, and a fluttering blast of air with long pre and post air blasts at 60psi were used to load a long length of tube as shown. This allowed for direct loading of the supply tube, but because of residue left inside the air blaster from previous runs, we can only report on the relative change in weight between runs. An unknown, but noticeable loss of powdered sugar was lost to the environment and test apparatus.

**Experimental Data**

*   **Corkscrew Configuration:**
    *   Initial weight: 13.206g
    *   Captured in corkscrew: 13.660g
    *   Difference (Pre/Post): 0.454g

*   **Trap Filter:**
    *   Initial weight: 41.566g
    *   Captured in trap filter: 41.591g
    *   Difference (Pre/Post): 0.025g

**Conclusion:** A ratio of **18.16 to 1** was calculated (Captured vs. Let Past).

### 7.2. Experimental Run: November 22, 2025

**Test Conditions**
*   Pressure: 1-7.5 psi (pressure regulator was not accurate at this level).

**Experimental Data**
*   **10 Micron Filter:**
    *   Pre-run weight: 41.575g
    *   Post-run weight: 41.666g
    *   Difference (Captured): 0.091g

*   **Corkscrew Filter:**
    *   Pre-run weight: 13.690g
    *   Post-run weight: 14.556g
    *   Difference (Captured): 0.866g

**Conclusion:**
(14.556 - 13.690) / (41.666 - 41.575) = 0.866 / 0.091
This results in a capture ratio of **9.736 : 1**.

### 7.3. Experimental Run: January 25, 2026

**Test Conditions**
*   **Material:** Cornstarch (4 Tablespoons initially in hopper).
*   **Pressure:** 0.04 PSI measured in 3/4" tube (used for estimating velocity). Compressor set to 30 psi (steady state) before gun opened; fluctuated 60-30 psi during pulsing.
*   **Agitation:** Agitated with mallet; tapping the gun followed by pulling the trigger proved most effective.

**Observations**
*   **10:33:** Gun opened and shaking began.
*   **10:35:** Agitated with mallet.
*   **10:37:** Experiment stopped.
*   **10:41 - 10:43:** Resumed with tapping.
*   **10:51:** Pressure fluctuation observed (60-30 psi) when trigger opened/pulsed. No noticeable change in regulator when pulsed with hammer.
*   **Failure Mode:** Corkscrew filter barb fitting broke at 10:53.

**Retention Analysis**
*   **Hopper:** Practically empty (2-3 tablespoons less than start).
*   **Gun:** Mostly empty (holds ~2 tablespoons).
*   **Post-Filter:** Less than 1 tsp found in the post-IF hose.

**Conclusion:**
The system appears to be less effective than the 1/4" version, likely due to the particulate filter catching significant fine particles.

### 7.4. Initial Tube Corkscrew Test

This test involved a non-optimal seal, as the O-ring geometry was not correct and print artifacts made it difficult to form a perfect seal. RTV silicone rubber was applied by hand to form a “good enough” seal.

**Notes:**
The outgoing air created a tight rotational vortex which kept the particles from coating the tube. A Dyson vacuum was used as the suction source. The slit didn’t capture particles as effectively as the other designs, but this was sized for larger particulates; a series of successively smaller baffles might produce better results. There were particles buffeted inside the tube. The clear tube made visual inspection of the airflow and dust-laden air possible. The geometry of the corkscrew may need to be further optimized. Being able to calculate the fluid flow should allow for optimal geometry generation. There’s the potential for machine learning parameter learning and auto parameter tuning.

**Conclusion:**
The pressure differential and accompanying speed definitely changed the ratio of captured material in the pre-filter vs the post-filter. We can conclude that the filter itself fundamentally works, but given the vastly different performance from the much larger vacuum filter, more work needs to be done to combine existing fluid flow theory with our parameterized 3D model.

### 7.5. Theoretical Interpretation of Experimental Results

To understand the "thinking" behind the separation efficiency of these helical systems, it is necessary to look at the dimensionless numbers that dictate particle behavior (defined in Appendix A.2). In a 3/4" helical channel, the transition from a 60 psi "blast" to a 7.5 psi steady flow fundamentally changes the fluid regime and the forces acting on the particles.

#### 1. Reynolds Number ($Re$): The Flow Regime
*   **At 60 psi:** With estimated velocities exceeding 40 m/s, the $Re$ is likely **>50,000**, placing the flow in a fully turbulent regime. Turbulence can be a "double-edged sword"; it keeps particles from settling but also creates "re-entrainment" where particles are kicked back out of traps.
*   **At 5–10 psi:** Velocities drop significantly (to 5–10 m/s), resulting in a $Re$ between **6,000 and 13,000**. While still turbulent, the lower kinetic energy reduces the impact of secondary mixing.

#### 2. Dean Number ($De$): The "Engine" of Separation
For a 3/4" tube ($D \approx 19$ mm) with a tight helical radius ($R_c \approx 25$ mm), the Dean number is approximately **32,000** at 60 psi.
*   **High Pressure:** $De \approx 32,000$. The vortices are extremely aggressive, sweeping the entire cross-section and slamming particles into the walls.
*   **Low Pressure:** $De \approx 4,000 - 8,000$. The vortices are present but far less energetic. This is why the separation ratio dropped from 18:1 to 9:1 in the steady-state tests—the "sweeping" action was simply too weak to overcome the air's viscosity.

#### 3. Stokes Number ($Stk$): Particle Tracking
*   **$Stk > 1$:** The particle has high inertia and will fly straight into a trap when the air turns.
*   **$Stk \ll 1$:** The particle follows the air perfectly and will bypass the traps.

At 60 psi, even fine 10-micron particles have enough momentum to reach a $Stk \approx 1.0$ threshold. At lower pressures ($Stk \approx 0.1 - 0.2$), they begin to behave like "gas," following the streamlines and escaping.

#### The Strategy: Multiple Corkscrews

The logic for using multiple corkscrews at lower pressure is to leverage **Cumulative Probability**. If a single stage at 10 psi has a 50% capture efficiency, adding stages works exponentially:

*   **1 Stage:** 50% captured
*   **2 Stages:** 75% captured
*   **3 Stages:** 87.5% captured

By using three chambers in series, the system can achieve the same "clean" output as a 60 psi blast but at a much lower, more manageable pressure that doesn't stress the 3D-printed seams or cause "puffing" of material into the environment.

### 7.6. Supplementary Materials

*   **Experimental Run 10/30/2025 Photo Album:** [https://photos.app.goo.gl/baQobViRN2EK12yL6](https://photos.app.goo.gl/baQobViRN2EK12yL6)
*   **Experimental Run 11/22/2025 Photo Album:** [https://photos.app.goo.gl/WuuFNhYvLVV2sVhG9](https://photos.app.goo.gl/WuuFNhYvLVV2sVhG9)
*   **Experimental Run 01/25/2026 Photo Album:** [https://photos.app.goo.gl/kphwWbPpzWjCYpaS9](https://photos.app.goo.gl/kphwWbPpzWjCYpaS9)

## 8. Conclusion and Recommendations

The OpenAuto-CFD framework, as demonstrated by the Corkscrew Filter case study, exhibits a high Technology Readiness Level (TRL) for an automated design framework. It successfully bridges the gap between parametric CAD and high-fidelity CFD using modern AI orchestration.

### 8.1. Technical Recommendations for Improvement
1.  **Convergence Criteria:** The `FoamDriver` currently runs for a fixed number of iterations. Implementing a residual-based stopping criterion (e.g., stop when residuals < $$10^{-4}$$) would optimize computational resource usage.

### 8.2. Recent Improvements
The following recommendations from previous evaluations have been successfully implemented:
1.  **Repository Integrity:** The missing `corkscrewFilter/constant` directory has been restored, ensuring the OpenFOAM simulation case is fully defined with `transportProperties` and `turbulenceProperties`.
2.  **WASM Portability:** The generation pipeline has been migrated to `openscad-wasm`, decoupling the runtime environment from local binary dependencies.
3.  **Standardized Configuration:** A scalable "Configuration-as-Code" structure (`configs/`) has replaced ad-hoc variable modification, enabling reproducible batch generation.
4.  **Lagrangian Turbulence:** The `StochasticDispersionRAS` model has been re-enabled in `kinematicCloudProperties`, allowing for accurate modeling of particle dispersion due to turbulent eddies.
5.  **Parallel Execution:** The optimization loop now supports concurrent simulation execution via asynchronous worker processes, significantly accelerating parameter space exploration.
6.  **Distributed Optimization:** A Git-based synchronization mechanism allows for distributed optimization across multiple machines, with results tracked via commit hashes.
7.  **Component Modularization:** The `Barb` generator and `FilterHolder` components have been fully parameterized and standardized, replacing hardcoded geometry.

---

## Appendix A: Advanced Inertial Filtration Architectures for Microgravity and Lunar Environments

**A Comprehensive Analysis of Helical Channel "Corkscrew" Separators**

### Executive Summary

The exploration of the lunar surface presents a unique and formidable challenge to Environmental Control and Life Support Systems (ECLSS): the omnipresent, abrasive, and cohesive threat of lunar regolith. As humanity prepares for sustained presence on the Moon under the Artemis program, the limitations of terrestrial filtration paradigms—specifically their reliance on gravity and disposable barrier media—have become critically apparent. This report presents an exhaustive technical analysis of helical channel centrifugal filtration systems, colloquially known as "corkscrew filters," as a robust alternative for orientation-agnostic, clog-resistant particulate separation.
The analysis is grounded in a specific experimental investigation involving the pneumatic conveyance of powdered sugar—a fine particulate proxy—through a three-chamber helical geometry at varying pressures (60 psi versus 1–10 psi). These experiments serve as a microcosm for the broader fluid dynamic challenges inherent in inertial separation: the necessity of achieving critical Reynolds (Re) and Dean (De) numbers to initiate stable particle migration against stochastic turbulence.
This document serves as a foundational chapter for a larger body of work on centrifugal filtration. It synthesizes experimental data with advanced fluid dynamics theory, specifically focusing on the generation of Dean vortices within curved geometries. These secondary flows offer a mechanism to direct contaminants away from the clean flow path, effectively transitioning filtration from a "barrier" methodology (pore exclusion) to a "force-field" methodology (inertial sorting).
Furthermore, this report critically evaluates the physicochemical properties of powdered sugar as a simulant for lunar regolith. While sugar effectively mimics the aerodynamic diameter of the hazardous respirable dust fraction (<20 µm), significant divergences in bulk density and electrostatic behavior necessitate careful calibration of experimental results when extrapolating to lunar conditions. The analysis concludes with optimized design parameters for a lunar-dust-rated corkscrew filter, integrating features such as stepped contours for particle trapping, conductive materials for electrostatic dissipation, and regenerative purge mechanisms to ensure indefinite operational lifespans.

### A.1. Introduction: The Imperative for Clog-Resistant, Orientation-Agnostic Filtration

**A.1.1 The Failure Modes of Traditional Filtration in Space**

Human spaceflight has historically relied on High-Efficiency Particulate Air (HEPA) filters and barrier media to maintain cabin air quality. While these systems have proven effective in the controlled environments of the Space Shuttle and the International Space Station (ISS), they face catastrophic limitations in long-duration exploration missions, particularly those targeting the lunar surface. The fundamental operational premise of barrier filtration—trapping particles within a fibrous matrix—creates a finite lifespan defined by saturation. Once the matrix is loaded, the pressure drop across the filter rises exponentially, necessitating replacement. In a mission scenario such as a Mars transit or a lunar outpost, the logistics of resupplying disposable filter cartridges are prohibitive, consuming valuable launch mass and volume.
The primary failure mode in lunar environments is particulate loading. On the Moon, the environment is dominated by lunar regolith—a jagged, electrostatically charged dust that pervades all mechanical seals and habitable volumes. Unlike terrestrial dust, which is often rounded by weathering, lunar dust retains sharp, abrasive edges due to its formation via micrometeoroid bombardment.<sup>[1](#ref-1)</sup> This ubiquitous, clinging dust caused a plethora of problems during the Apollo missions, compromising seals, abrading spacesuit fabrics, and posing significant health risks including "lunar dust hay fever." Standard HEPA filters, while capable of capturing these particles, would become clogged rapidly given the high concentration of dust anticipated in airlocks and suit preparation areas.<sup>[2](#ref-2)</sup> The operational data from Apollo suggests that the dust's unique properties allow it to bypass standard mitigation techniques, necessitating a filtration approach that does not rely on a consumable media matrix.
The second critical failure mode is gravity dependence. Many terrestrial inertial separators, such as standard industrial cyclones, rely partially on gravity to settle the separated "dust cake" into a hopper. In microgravity (0g) or reduced gravity (1/6g on the Moon), these gravitational forces are effectively absent.<sup>[3](#ref-3)</sup> A standard cyclone operating in microgravity faces the risk of re-entraining separated particles into the vortex finder if the centrifugal forces are not sufficient to substitute for gravitational settling. The distinct lack of a "down" vector means that separated particles do not naturally fall into a collection bin; they must be actively driven there by fluid forces. Consequently, any filtration system designed for the Moon must be "orientation agnostic," capable of functioning regardless of the spacecraft's attitude or the local gravity vector.<sup>[4](#ref-4)</sup>

**A.1.2 The "Corkscrew" Solution: Helical Inertial Filtration**

The "corkscrew filter," a technology notably advanced by NASA Johnson Space Center and IRPI, LLC, addresses these limitations through a multi-phase flow separation method.<sup>[5](#ref-5)</sup> This technology represents a paradigm shift from barrier filtration to inertial separation. Unlike a barrier filter, which physically obstructs the flow to trap particles, a corkscrew filter structures the flow itself to fling particles into specific trapping zones. The design utilizes a helical flow path to generate continuous centrifugal force. This force acts as an "artificial gravity," driving denser phases (liquids or solids) toward the channel walls regardless of the spacecraft's orientation.<sup>[6](#ref-6)</sup>
The key innovation in these designs distinguishes them from simple coiled tubes. The "corkscrew" architecture often incorporates stepped contours or wicking walls that capture the separated material.<sup>[5](#ref-5)</sup> As the aerosol traverses the helical path, the centrifugal force pushes the denser particles into these recessed traps. Once a particle enters the trap, it is shielded from the high-velocity main flow, preventing re-entrainment. This mechanism allows the filter to operate continuously without a rise in pressure drop, as the primary flow channel remains unobstructed even as the traps fill. This "clog-free" characteristic is paramount for life support systems that must operate for months or years without maintenance.<sup>[7](#ref-7)</sup>
The application of this technology extends beyond simple dust removal. The initial development of the corkscrew filter was driven by the need to separate liquid water from the cabin atmosphere following a fire event and the discharge of a water-based fire extinguisher.<sup>[6](#ref-6)</sup> In such a scenario, the filter must handle a multi-phase mixture of gas, liquid water, and smoke particulates. The helical geometry proved capable of separating these phases by leveraging their density differences, sequestering the liquid into wicking materials while allowing the gas to pass through. This capability to handle "wet" filtration makes the corkscrew filter uniquely suited for the complex, unpredictable environment of a spacecraft emergency.

**A.1.3 Report Objectives**

This report aims to provide a comprehensive analysis of helical channel filtration, structured around the following objectives:
Deconstruct the Physics: To elucidate the complex fluid dynamics of helical flows, with a specific focus on the generation and manipulation of Dean vortices and their role in particle trapping.
Analyze Experimental Parameters: To rigorously evaluate the experimental conditions (60 psi vs. 1–10 psi) and explain the performance differentials observed with powdered sugar based on Reynolds and Dean number thresholds.
Evaluate Material Proxies: To critically assess the validity of using powdered sugar as a simulant for lunar regolith in filtration studies, accounting for differences in density, shape, and cohesion.
Design for the Moon: To propose optimized design parameters for a lunar-dust-rated corkscrew filter, addressing the unique challenges of regolith cohesion, electrostatic adhesion, and vacuum stability.

### A.2. Fluid Dynamics of Helical Channels: The Physics of Separation

To understand the operational mechanics of the corkscrew filter—and to interpret the stark difference in experimental results between 60 psi and 1–10 psi—one must delve into the fluid dynamics of curved pipes. The flow regime in a helical channel is fundamentally distinct from the Poiseuille flow observed in straight pipes due to the emergence of curvature-induced secondary flows. These secondary flows are not merely parasitic disturbances; they are the primary mechanism driving separation efficiency in helical inertial microfluidics.<sup>[8](#ref-8)</sup>

**A.2.1 The Dean Mechanism and Secondary Flows**

When a fluid flows through a curved channel, the interplay between centrifugal forces and pressure gradients creates a distinct secondary flow pattern. Fluid elements near the center of the channel, possessing higher velocity, experience a larger centrifugal force ($F_c \propto U^2/R$) than the slower-moving fluid near the channel walls. This force differential drives the core fluid outward toward the concave (outer) wall of the bend. To satisfy the conservation of mass (continuity), the fluid near the top and bottom walls must recirculate inward toward the convex (inner) wall to replace the displaced fluid.

**Reynolds Number ($Re$)**
The flow regime is fundamentally governed by the Reynolds number, which determines whether the flow is laminar or turbulent:
$$ Re = \frac{\rho U D_h}{\mu} $$
Where $\rho$ is density, $U$ is velocity, $D_h$ is the hydraulic diameter, and $\mu$ is dynamic viscosity.

This recirculation results in a pair of counter-rotating vortices known as Dean vortices.<sup>[9](#ref-9)</sup> These vortices are superimposed on the primary axial flow, creating a double-helical streamline pattern for the fluid itself. The fluid spirals as it moves downstream, effectively sweeping the cross-section of the channel. The strength and stability of these vortices are characterized by the dimensionless Dean number ($De$):

$$De = Re \sqrt{\frac{D_h}{2R_c}}$$
Where:
$D_h$ is the hydraulic diameter of the channel.
$R_c$ is the radius of curvature of the helix.
The separation efficiency of a corkscrew filter is critically dependent on $De$. The magnitude of the secondary flow velocity scales with the Dean number (approximately $U_{Dean} \sim De^2$).<sup>[10](#ref-10)</sup> Below a critical Dean number, the secondary flows are too weak to transport particles effectively across the primary streamlines against the forces of Brownian motion and diffusion. This theoretical threshold explains the experimental divergence: at 60 psi, the velocity $U$ is high, yielding a high $Re$ and consequently a high $De$, which drives robust separation. At 1–10 psi, the $De$ likely falls below the threshold required to initiate stable inertial migration, resulting in poor or negligible separation.<sup>[11](#ref-11)</sup>

**A.2.2 Particle Migration Forces in Helical Geometries**

In a helical filter, a solid particle is subject to a complex balance of forces that dictates its trajectory. The "clog-free" nature of the device depends on these forces effectively dominating the particle's motion, ensuring it is directed toward the trapping zones rather than remaining entrained in the clean gas stream.

**Stokes Number ($Stk$)**
The ability of a particle to follow fluid streamlines is characterized by the dimensionless Stokes number:

$$ Stk = \frac{\tau_p U}{D_h} = \frac{\rho_p d_p^2 U}{18 \mu D_h} $$

Where $\tau_{p}$ is the particle relaxation time, $d_{p}$ is particle diameter, and $\rho_{p}$ is particle density.
*   $Stk \ll 1$: Particles follow streamlines (no separation).
*   $Stk > 1$: Particles detach due to inertia (separation).

*   **Centrifugal Force (Primary Separation Force):** The dominant force driving separation in macro-scale helical filters is the centrifugal force generated by the primary flow curvature. This force acts radially outward, pushing denser particles toward the outer wall of the channel. The magnitude of this force is given by:

    $$F_{centrifugal} = (\rho_p - \rho_f) V_p \frac{U_\theta^2}{R}$$
    Where $\rho_p$ and $\rho_f$ are the densities of the particle and the fluid, respectively, $V_p$ is the particle volume, and $U_\theta$ is the tangential velocity of the fluid.
    **Implication for Operation:** Heavier particles (like powdered sugar or lunar regolith) are flung toward the outer wall. Crucially, this force is proportional to the square of the velocity ($U^2$). A reduction in pressure from 60 psi to 10 psi results in a significant decrease in flow velocity, which in turn causes a quadratic drop in the separation force. This physics confirms why the high-pressure run is essential for successful filtration; the low-pressure run simply does not generate sufficient g-forces to separate the solid phase from the gas phase.<sup>[12](#ref-12)</sup>

*   **Dean Drag Force:** The secondary Dean vortices exert a viscous drag force on the particles, pulling them laterally across the channel cross-section. This force is described by Stokes' drag law tailored for the transverse velocity field:

    $$F_{Dean} = 3 \pi \mu d_p U_{Dean}$$
    Where $U_{Dean}$ is the transverse velocity of the Dean vortices.<sup>[10](#ref-10)</sup>
    **Implication for Fine Particles:** For very small particles (typically <10 µm), the Dean drag force can rival or even exceed the centrifugal force. Dean vortices can entrain these fine particles and circulate them within the vortices, potentially trapping them in the vortex cores or remixing them if the filter geometry isn't tuned. However, in optimized designs, Dean vortices effectively "sweep" particles toward specific equilibrium positions. In microfluidic applications, this effect is used to focus particles into tight bands, allowing them to be "skimmed" off into separate outlets.<sup>[8](#ref-8)</sup>

*   **Inertial Lift Forces:** Close to the channel walls, particles experience inertial lift forces arising from the shear gradient of the fluid flow. The shear-gradient lift force pushes particles toward the channel walls, where the shear rate is highest. Conversely, the wall-induced lift force repels particles away from the wall due to the pressure buildup between the particle and the boundary.
    **Net Effect:** In helical channels, the interplay of Dean drag and inertial lift forces creates stable equilibrium positions. At high Reynolds numbers (Re > 50), these forces act to focus particles into distinct streamlines. This phenomenon is exploited in "inertial microfluidics" to separate particles based on size, as the equilibrium position is size-dependent.<sup>[11](#ref-11)</sup> For the corkscrew filter, these lift forces help keep larger particles moving along the wall (where the traps are located) while preventing them from becoming re-entrained in the center of the channel.

**A.2.3 The "Clog-Free" Dynamic**

The design requirement for a filter that "cannot be clogged" implies a system where particles are continuously removed or stored in a "dead zone" that does not impede the primary flow path. In barrier filters, the particles become the obstruction. In the corkscrew filter, the particles are moved out of the flow.
In the NASA/IRPI Corkscrew Filter, this is achieved via stepped contours or helical baffles.<sup>[5](#ref-5)</sup>
*   **Separation Mechanism:** The centrifugal force drives particles to the outer wall.
*   **Trapping Mechanism:** The outer wall is not a smooth arc; it contains a recessed step, a gutter, or a wicking (porous) layer. Once a particle crosses the streamline into this recessed zone, it enters a region of low velocity. The step shields the particle from the high-shear main flow, preventing re-entrainment.
*   **Prevention of Clogging:** Because the particles are sequestered in a recess (or "trap") while the main gas flow continues down the center of the channel, the pressure drop remains constant until the trap is physically 100% full. Unlike a HEPA filter, which begins to choke flow as soon as surface coverage begins, the corkscrew filter maintains 100% flow conductance even as it loads. The capacity of the filter is defined by the volume of these gutters, not by the surface area of a media. This geometric decoupling of "flow path" and "storage volume" is the essence of its clog-free performance.

### A.3. Experimental Analysis: The Powdered Sugar Proxy

The experimental setup employs powdered sugar as a test medium to evaluate the corkscrew filter's performance. To draw meaningful conclusions for space applications, it is essential to analyze the validity of this proxy and interpret the pressure-dependent results through the lens of fluid mechanics.

**A.3.1 Physicochemical Comparison: Sugar vs. Lunar Regolith**

To validate the experimental results, we must rigorously compare the physical properties of powdered sugar to the target contaminant: lunar dust (regolith).

**Table 1: Comparative Properties of Powdered Sugar and Lunar Regolith Simulants**

| Property | Powdered Sugar (Confectioners) | Lunar Regolith (Simulant JSC-1A / Highland) | Implication for Filtration |
| :--- | :--- | :--- | :--- |
| **Particle Size (D50)** | ~10–15 µm <sup>[14](#ref-14)</sup> | 40–130 µm (bulk), <20 µm dust fraction is critical <sup>[15](#ref-15)</sup> | Sugar is an excellent size proxy for the hazardous "respirable" fraction of lunar dust. |
| **Particle Size (D90)** | ~40–50 µm <sup>[14](#ref-14)</sup> | ~500 µm (coarse fraction included) <sup>[17](#ref-17)</sup> | Sugar lacks the coarse grit of raw regolith, meaning it tests the hardest filtration case (fines). |
| **Bulk Density (Loose)** | ~0.56 g/cm³ <sup>[18](#ref-18)</sup> | ~1.50 g/cm³ <sup>[19](#ref-19)</sup> | **Critical Divergence.** Regolith is ~3x denser. Centrifugal separation will be easier with regolith than sugar for the same size. |
| **Particle Shape** | Crystalline, semi-regular | Angular, jagged, agglutinates (glassy) <sup>[19](#ref-19)</sup> | Regolith is more abrasive and prone to mechanical interlocking (clogging). |
| **Cohesion** | High (hygroscopic clumping) | High (electrostatic + vacuum adhesion) <sup>[3](#ref-3)</sup> | Both are cohesive, but mechanisms differ. Sugar clumps due to moisture; regolith due to electrostatics. |

**Insight:** The use of powdered sugar represents a conservative test for centrifugal separation efficiency. Centrifugal force is directly proportional to the density difference between the particle and the fluid ($F \propto \rho_p - \rho_f$). Since sugar (approx. 1.6 g/cm³ particle density, 0.56 g/cm³ bulk density) is significantly less dense than lunar regolith (approx. 2.9 g/cm³ particle density, 1.5 g/cm³ bulk density), the forces acting on a sugar particle will be weaker than those on a regolith particle of the same size. Therefore, a filter geometry that successfully separates powdered sugar will almost certainly separate lunar dust even more effectively. However, the hygroscopic nature of sugar may lead to "caking" in the traps that mimics the cohesive behavior of lunar dust, albeit through a moisture-driven mechanism rather than the electrostatic mechanism prevalent on the Moon.

**A.3.2 Analysis of the "60 psi" vs "1-10 psi" Runs**

Experimental runs were conducted at two distinct pressure regimes: 60 psi and 1–10 psi. The vast difference in outcome between these two conditions is physically deterministic and aligns with the theoretical constraints of inertial separation.

*   **High Pressure (60 psi) - The Inertial Regime**
    *   At 60 psi, the air velocity within the filter assembly (assuming a standard hose diameter of 0.25" to 0.5") is substantial, likely reaching highly turbulent flow conditions.
    *   **Reynolds Number:** High velocity ($U$) implies a high Reynolds number ($Re > 4000$).
    *   **Separation Physics:** As noted in the literature, particle separation efficiency in helical channels peaks at Re > 50–100.11 At these Reynolds numbers, the inertial lift forces (which scale with $Re^2$) and centrifugal forces are maximized.
    *   **Result:** The 60 psi run likely generated strong, stable Dean vortices and sufficient centrifugal force to fling the sugar particles to the channel walls. If the hose had any curvature (coiling) and the filter included trapping features, the sugar would have stratified rapidly, explaining the successful collection.

*   **Low Pressure (1-10 psi) - The Diffusive/Laminar Regime**
    *   At 1–10 psi, the flow velocity is drastically reduced, likely by an order of magnitude or more compared to the 60 psi case.
    *   **Reynolds Number:** The Reynolds number drops significantly, potentially into the laminar or transitional regime.
    *   **Separation Physics:** Below a critical Re, inertial migration forces become negligible compared to viscous drag. The particles tend to follow the fluid streamlines (Stokes regime) rather than crossing them to reach the walls.<sup>[21](#ref-21)</sup> The Dean vortices, if present, are weak and unable to transport particles effectively against diffusion.
    *   **Result:** The sugar likely remained entrained in the airflow, behaving as a tracer rather than a separated phase. This confirms that corkscrew filters are velocity-dependent devices. They require a minimum flow rate (critical velocity) to "switch on" the separation physics.

*   **The "Hose" Factor**
    *   The experiment involved "filling a hose" with sugar. In a flexible hose, the radius of curvature ($R_c$) is variable and potentially large.
    *   **Torsion and Helicity:** If the hose was coiled, it acted as a helical channel. However, if the coiling radius was too large (large $R_c$), the centrifugal force ($U^2/R_c$) would diminish.
    *   **Roughness and Trapping:** Standard hoses are smooth-walled. The NASA corkscrew filter relies on stepped contours.<sup>[5](#ref-5)</sup> In a smooth hose, sugar might be flung to the wall by centrifugal force but then simply slide along the wall and re-entrain at the outlet due to shear flow. Without a physical trap (wicking material or a step), separation in a smooth hose is temporary and unstable.

### A.4. The Design of the "Corkscrew" Filter: Anatomy of a Clog-Free System

The "corkscrew filter" is not merely a coiled tube; it is a precision-engineered multiphase separator designed to handle complex mixtures of gas, liquid, and solids. Based on the NASA/IRPI patents and technical descriptions <sup>[5](#ref-5)</sup>, the design consists of three critical subsystems that work in concert to achieve high efficiency and clog resistance.

**A.4.1 The Helical Flow Path (The Accelerator)**

The core of the filter is a multi-channel helix. Unlike a single spiral tube, these filters often employ multiple parallel helical channels (a "multi-start" helix) to maximize the surface area available for separation and increase throughput while maintaining a small hydraulic diameter ($D_h$).
*   **Function:** The primary function of the helix is to accelerate the aerosol and generate sustained g-forces.
*   **Design Constraint:** The pitch and radius of the helix must be constant to maintain stable Dean vortices. Variable curvature can lead to vortex breakdown and remixing of the separated phases.<sup>[11](#ref-11)</sup> The curvature induces the secondary flows that sweep the channel cross-section, moving particles towards the trapping zones.

**A.4.2 The Stepped Contour (The Trap)**

This is the defining feature that allows for "clog-free" operation and distinguishes the corkscrew filter from simple inertial separators.
*   **Geometry:** The outer wall of the helical channel is not a smooth arc. Instead, it features a "step," "gutter," or "recess" that is set back from the main flow path.
*   **Mechanism:** Centrifugal force drives particles radially outward. As they migrate to the outer wall, they cross the streamline that divides the main flow from the recessed trap. Once inside the gutter, the boundary layer velocity is significantly lower. The step acts as a shield, protecting the trapped particles from the high-shear main flow.
*   **Clogging Resistance:** Because the main flow path remains unobstructed, the pressure drop across the filter does not rise as the traps fill. The capacity of the filter is limited only by the volume of these gutters. Even as the gutters fill with dust, the gas continues to flow unimpeded down the center of the channel.

**A.4.3 The Wicking/Porous Wall (Phase Separation)**

In the original NASA application for separating liquid water (from fire extinguishers), the trap walls were lined with a hydrophilic wicking material.<sup>[7](#ref-7)</sup>
*   **Mechanism:** Liquid droplets impinging on the wall wet the surface and are wicked away by capillary action into a storage reservoir. This effectively separates the liquid phase from the gas phase.
*   **Solid Application:** For solid particulates like lunar dust, the wicking material might be replaced by a porous metal sinter or a magnetic trap (leveraging the iron content of regolith). A porous wall allows a small amount of gas to bleed off through the trap, creating a net flow vector into the trap that helps retain the solids.<sup>[12](#ref-12)</sup> This "bleed flow" effectively concentrates the dust cake against the wall.

**A.4.4 Comparison to Cyclones**

While sharing the fundamental principle of centrifugal separation, the corkscrew filter offers distinct advantages over standard cyclone separators for space applications:
*   **Residence Time:** The helical path is significantly longer than the body of a standard cyclone, providing a longer residence time for separation forces to act on the particles.<sup>[22](#ref-22)</sup> This allows for the separation of finer particles than a cyclone of comparable diameter.
*   **Orientation Agnostic:** Cyclones typically rely on gravity to pull the separated "dust cone" down into the hopper. In microgravity, the dust can hover in the separation zone and be re-entrained. The corkscrew filter uses the flow's own momentum and the stepped trap geometry to sequester particles, making it fully functional in zero gravity.<sup>[23](#ref-23)</sup>

### A.5. Application: Lunar Regolith and Space Exploration

The ultimate goal is to apply this filtration technology to the challenge of moon dust. This application introduces extreme environmental variables—specifically abrasion, electrostatics, and vacuum—that the powdered sugar experiment does not capture.

**A.5.1 The Lunar Dust Threat**

Lunar dust is widely recognized as one of the primary hazards to lunar exploration. Its properties are uniquely challenging:
*   **Abrasive:** Formed by continuous micrometeoroid bombardment, lunar dust particles are jagged shards of glass and agglutinates. They act like microscopic knives, shredding soft materials such as seals and fabrics.<sup>[1](#ref-1)</sup>
*   **Electrostatic:** The lunar surface is exposed to the solar wind and UV radiation, which charge the dust particles. This "triboelectric charging" causes the dust to cling tenaciously to surfaces, making it difficult to remove mechanically.<sup>[24](#ref-24)</sup>
*   **Respiring Hazard:** The fine fraction (<20 µm) is particularly dangerous as it can settle deep in the lungs, posing long-term health risks to astronauts.

**A.5.2 Electrostatic Challenges in Inertial Filtration**

In a helical filter, triboelectric charging can be a significant complicating factor.
*   **The Problem:** The high-velocity transport of dielectric dust (regolith) through dielectric channels (plastic or polymer 3D prints) generates massive static charges due to contact electrification. The dust may adhere to the channel walls before reaching the trap, or clump together in unpredictable ways. This adhesion can alter the effective geometry of the channel, potentially leading to clogging or flow disruption.
*   **The Solution:** The filter walls must be made of conductive materials and grounded to dissipate charge. Alternatively, electrostatic precipitation principles can be integrated into the design. By applying a voltage to the helical walls, the separation efficiency for the finest particles (which are the hardest to separate inertially) can be boosted.<sup>[26](#ref-26)</sup> The helical channel can act as a long electrostatic precipitator, attracting charged dust particles to the walls.

**A.5.3 Simulant Fidelity: JSC-1A vs. Sugar**

While sugar was employed for initial testing, future validation must transition to high-fidelity lunar simulants.
*   **JSC-1A:** This is a standard mare simulant with a basaltic composition that replicates the density, chemical composition, and abrasiveness of Moon dust.<sup>[19](#ref-19)</sup>
*   **Density Factor:** As noted in [27](#ref-27), simulants like OB-1A and JSC-1A have particle densities of ~2.9 g/cm³ and bulk densities of ~1.5–1.7 g/cm³. This density difference is critical for inertial separation calculations.
*   **Calculation:** The centrifugal force on a regolith particle ($F_{regolith}$) compared to a sugar particle ($F_{sugar}$) of the same size is approximately:
    $$ \frac{F_{regolith}}{F_{sugar}} = \frac{\rho_{regolith} - \rho_{air}}{\rho_{sugar} - \rho_{air}} \approx \frac{2.9}{0.56} \approx 5.1 $$
*   **Conclusion:** A corkscrew filter that is optimized for sugar will be 5 times more effective (in terms of force magnitude) when separating lunar regolith. The successful separation of sugar at 60 psi is therefore a very positive indicator for the system's potential performance with lunar dust.

**A.5.4 "Filtration That Cannot Be Clogged"**

For a permanent lunar outpost, "cannot be clogged" implies a system that is regenerative. A trap that fills up is eventually a clog.
*   **The Scroll Filter Concept:** NASA Glenn has developed systems where the "trap" media is a scroll that can be advanced to a clean section automatically.<sup>[28](#ref-28)</sup>
*   **The Corkscrew Adaptation:** The helical traps could be designed with a "bleed" flow or an active purge. A small fraction of the air (5–10%) could continuously flush the trapped dust into a high-density storage bag or a vacuum port. This "active purge" would render the filter truly non-clogging, as the traps would never reach capacity.<sup>[29](#ref-29)</sup>

### A.6. Comparative Performance Analysis

**Table 2: Technology Comparison for Space Filtration**

| Feature | Corkscrew Filter (Helical) | Conventional Cyclone | HEPA / Barrier Filter | Electrostatic Precipitator |
| :--- | :--- | :--- | :--- | :--- |
| **Separation Principle** | Centrifugal + Dean Vortices | Centrifugal + Gravity | Physical Interception | Electrostatic Attraction |
| **Pressure Drop** | Low, Constant <sup>[30](#ref-30)</sup> | Moderate to High | Increases w/ Loading | Low |
| **Clog Resistance** | High (Open Channel) | Moderate (Outlet clogging) | Low (Pore blocking) | High (Plate cleaning needed) |
| **Gravity Dependence** | None (Orientation Agnostic) | High (typ. uses gravity) | None | None |
| **Cut-Point (Efficiency)** | High for >2 µm <sup>[31](#ref-31)</sup> | High for >5–10 µm <sup>[32](#ref-32)</sup> | High for >0.3 µm | High for <1 µm |
| **Lunar Dust Suitability** | Excellent (Pre-filter) | Good (Pre-filter) | Poor (Primary) / Good (Final) | Excellent (Fine fraction) |
| **Maintenance** | Passive / Regenerative | Passive / Hopper Emptying | Consumable Replacement | Plate Cleaning |

**Key Insight:** The corkscrew filter sits in the "sweet spot" as a pre-filter. It protects the HEPA filter. A standalone HEPA filter on the Moon would clog in hours due to the high dust load. A corkscrew filter upstream removes 90–95% of the mass (the coarse and medium dust), allowing the HEPA to function for months or years handling only the sub-micron fines.<sup>[28](#ref-28)</sup>

### A.7. Second and Third-Order Insights

**A.7.1 The Thermodynamics of Compression**

The 60 psi experiment introduces a thermodynamic variable that may have influenced the results. Compressing air to 60 psi heats it. Expanding it through a nozzle or filter cools it rapidly.
*   **Moisture Risk:** If the compressed air used in the experiment contained humidity (typical of Earth air), the rapid expansion in the filter could condense water vapor. Powdered sugar is highly hygroscopic.
*   **Risk:** The "clogging" or "caking" observed in low-pressure runs (or potentially in high-pressure runs if not careful) might not be purely mechanical, but chemical—the formation of sugar syrup or cement in the channels due to moisture.
*   **Space Context:** Lunar air is dry, but cabin air has humidity. The "wicking" walls of the NASA design are specifically intended to handle this condensation/liquid phase.<sup>[5](#ref-5)</sup> This feature turns a potential failure mode (condensation) into a functional capability (humidity control), allowing the filter to manage both dust and excess moisture.

**A.7.2 Acoustophoretic Hybridization**

The literature suggests that helical channels are often combined with acoustophoretic separation (sound waves) in microfluidic applications.<sup>[11](#ref-11)</sup>
*   **Future Insight:** For a lunar base, combining a corkscrew filter with ultrasonic transducers could create a "solid-state" filter with no moving parts that separates particles based on compressibility as well as density. This hybrid approach could help separate biological contaminants (skin flakes) from regolith, which is useful for recycling resources and characterizing the cabin environment.

**A.7.3 The "Dean Drag" Limit**

There is a theoretical limit to corkscrew filtration efficiency for ultrafine particles. As particles get smaller (<1 µm), the Dean drag forces (recirculation) begin to overpower the centrifugal forces.
*   **Implication:** The corkscrew filter cannot be the only filter in a life support system. It must be part of a series architecture: Corkscrew (Bulk Removal) -> Electrostatic (Fines) -> HEPA (Polishing). The goal of a single "uncloggable" filter is achievable for bulk dust removal, but not for sterilization grade air quality. The system must be viewed as a bulk separator that enables the longevity of the finer polishing filters.

### A.8. Recommendations for the Final Report

Based on this analysis, the following recommendations are made for the final report and design iteration:
1.  **Adopt the "Stepped" Geometry:** The "hose" experiment likely lacked the precision stepped traps of the NASA design. Future prototypes should use 3D-printed helical inserts with defined particle traps (gutters) to prevent re-entrainment and ensure true clog-free performance.
2.  **Maintain High Reynolds Number:** The experimental data confirms that high pressure (high velocity) is non-negotiable for this scale of device. For space applications, this implies the filter should be placed on the high-pressure side of circulation fans or compressors, rather than the suction side, to ensure sufficient $De$.
3.  **Transition to Dense Simulants:** Move from sugar to a sand or regolith simulant (like JSC-1A or even fine silica sand) to better model the density-driven separation forces. This will provide more realistic efficiency data for lunar applications.
4.  **Integrate Conductive Materials:** To address the electrostatic adhesion of lunar dust, the filter body should be printed in conductive PLA or machined aluminum and grounded. This will prevent static buildup and potential clogging due to triboelectric charging.
5.  **Focus on "Regenerative" Traps:** Design the trap sections to be purgeable. A simple valve that opens to vacuum (space environment) or a secondary collection bag could instantly suck the trapped dust out of the filter, cleaning it without disassembly.

### A.9. Conclusion

The "corkscrew" helical channel filter represents a robust, gravity-independent solution to the problem of particulate filtration in space exploration. The experiment with powdered sugar effectively demonstrates the fundamental dependency of this technology on inertial velocity (pressure). While 1–10 psi flows fail to generate the necessary Dean vortices and centrifugal forces for separation, 60 psi flows successfully activate the inertial separation regime.
For lunar applications, the corkscrew filter offers a critical advantage: the ability to separate the abrasive, dense bulk of lunar regolith without the clogging inevitable with barrier filters. By refining the geometry to include stepped traps and leveraging the high density of regolith, this technology can serve as the primary defense line in Environmental Control and Life Support Systems (ECLSS) for the Artemis generation of lunar habitats.

---

## Part B: Real-Time Multi-Physics Surrogate, PINN Conservation & Agentic CAD Architecture

### B.1. Multi-Physics Surrogate & Exact Differentiable Gradients

High-fidelity OpenFOAM and CalculiX simulations require significant wall-clock compute (15–45 minutes per run). To achieve sub-second exploration and interactive visualization, the system implements a Universal Multi-Physics Radial Basis Function (RBF) Surrogate (`surrogate_multiphysics.py`) supporting fluid dynamics (CFD), structural mechanics (FEA), and high-frequency electromagnetics (EM).

#### Exact Analytic Radial Basis Derivatives
Rather than relying on noisy numerical finite differences, exact analytical gradients $\nabla_{\mathbf{p}} J$ are derived on the surrogate response surface (`surrogate_gradients.py`):
For an RBF interpolator with kernel $\phi(r)$ where $r = \|\mathbf{x} - \mathbf{x}_j\|$:
$$\frac{\partial y}{\partial x_i} = \sum_{j=1}^N w_j \frac{\phi'(r_j)}{r_j} (x_i - x_{j,i}) + \sum_{k=1}^d c_k \frac{\partial p_k(\mathbf{x})}{\partial x_i}$$
For the Thin-Plate Spline kernel $\phi(r) = r^2 \ln(r)$ with scaling parameter $\epsilon$:
$$\frac{\phi'(r)}{r} = \epsilon^2 (2 \ln(\epsilon r) + 1)$$
Analytic derivatives achieve numerical parity with centered finite differences down to machine precision ($\approx 10^{-10}$ relative error). This enables the `DifferentiableInverseDesigner` to execute multi-start L-BFGS-B gradient search, converging to Pareto-optimal designs in less than $10\text{ ms}$.

### B.2. Multi-Fidelity Mesh Pyramid (Co-Kriging & Two-Stage Active Screening)

To minimize the total number of expensive fine-mesh simulations, the system adopts a Kennedy & O'Hagan Co-Kriging framework (`surrogate_multifidelity.py`, `multifidelity_driver.py`, `model_fusion_multifidelity.py`):
$$y_H(\mathbf{p}) = \rho \cdot y_L(\mathbf{p}) + \delta(\mathbf{p})$$
1. **Tier 1 (Coarse)**: $4.8\text{ mm}$ background mesh, 120 iteration limit, relative compute cost $\approx 3\%$.
2. **Tier 2 (Fine)**: $1.5\text{ mm}$ boundary-layer resolving mesh, full convergence, relative compute cost $= 100\%$.
3. **Two-Stage Active Screening**:
   - Every candidate geometry proposed by the optimizer is evaluated on Tier 1 first.
   - If the candidate fails physical feasibility thresholds (e.g. separation efficiency $\eta < 89\%$ or pressure drop $\Delta P > 4500\text{ Pa}$), it is immediately pruned (`PRUNED_COARSE`).
   - Only promising candidates are promoted to Tier 2 (`PROMOTED_TO_FINE`), delivering a verified **$2.9\times$ computational speedup** across optimization campaigns.

### B.3. Physics-Informed Conservation Regularizer (PINN)

Data-driven interpolators can generate unphysical artifacts such as mass-divergence in velocity fields or non-equilibrium stress spikes. The `pinn_conservation.py` engine enforces fundamental physical conservation laws:

#### 1. Fluid Incompressibility via Discrete Helmholtz-Hodge Solenoidal Projection
By the Helmholtz-Hodge theorem, any 3D vector field $\mathbf{u}$ on an unstructured point cloud decomposes into a divergence-free (solenoidal) field and a dilatational potential gradient:
$$\mathbf{u} = \mathbf{u}_{\text{sol}} + \nabla \phi \quad \text{where} \quad \nabla \cdot \mathbf{u}_{\text{sol}} = 0$$
Using Discrete Exterior Calculus over $k$-nearest neighbor stencils, the discrete divergence operator $D \in \mathbb{R}^{N \times 3N}$ and its adjoint gradient $D^T$ define the discrete Laplace-Beltrami operator $L = D D^T$. The projection is obtained by solving:
$$(D D^T) \boldsymbol{\lambda} = D \mathbf{u} = \text{div}(\mathbf{u})$$
$$\mathbf{u}_{\text{sol}} = \mathbf{u} - D^T \boldsymbol{\lambda}$$
This guarantees exact mass conservation ($\nabla \cdot \mathbf{u}_{\text{sol}} \approx 0$), eliminating $100\%$ of unphysical dilatational divergence down to solver tolerance ($10^{-10}$) in $<25\text{ ms}$.

#### 2. Cauchy Stress Static Equilibrium
Evaluates structural admissibility under linear elasticity:
$$\nabla \cdot \boldsymbol{\sigma} + \mathbf{f} \approx \mathbf{0}$$
where $\boldsymbol{\sigma} = \lambda \text{tr}(\boldsymbol{\varepsilon})\mathbf{I} + 2\mu \boldsymbol{\varepsilon}$. Unphysical stress discontinuities are penalized directly in the acquisition objective.

### B.4. LLM Tool-Calling Integration (Kimi K3 / Gemini CAD Agent)

To enable autonomous engineering workflows, the platform provides native function-calling tools (`cad_agent_tools.py`) matching the OpenAPI / JSON Schema standard accepted by Kimi K3, Google Gemini, and OpenAI-compatible models:

| Tool Name | Purpose | Output |
| :--- | :--- | :--- |
| `predict_surrogate` | Sub-second CFD/FEA evaluation | Predicted metrics + Epistemic uncertainty |
| `run_inverse_design` | Differentiable L-BFGS-B gradient search | Optimal parameters + Convergence score |
| `check_physics_conservation` | Evaluates $\nabla \cdot \mathbf{u}$ & stress equilibrium | Continuity loss + Admissibility flag |
| `dispatch_simulation` | Non-blocking background solver dispatch | Unique `job_id` + Queue status |
| `check_simulation_status` | Asynchronous worker pool query | Status (`COMPLETED`/`RUNNING`) + Metrics |
| `generate_scad_code` | Manifold check & OpenSCAD compilation | Validated `.scad` script path |

The `CADReasoningAgent` executes multi-turn design campaigns: reasoning through trade-offs, verifying physical conservation, validating geometric manifold constraints, and generating verified 3D printable CAD models without human intervention.

### B.5. Interactive Real-Time WebGL HUD (Atlas Viewer)

The real-time visualization layer (`viewer/web/`, `viewer/server.py`) provides an in-browser engineering console:
- **60 FPS Parameter Scrub**: Scrub geometric sliders (revolutions, radii, pitch, chamfers) with immediate surrogate field updates.
- **Dynamic Particle Streamline Ribbons**: Particle trajectories computed via Runge-Kutta 4 integration through the solenoidal velocity field.
- **Stress Heatmaps**: Colormapped FEA surface von Mises stresses (`Turbo`, `Viridis`, `Plasma`, `Twilight`).
- **Binary GPU Buffer Streaming**: Efficient `.bin` field buffer streaming reducing network serialization overhead by $>85\%$.

---

### A.10. Works Cited

1.  dust mitigation: lunar air filtration with a permanent-magnet system (laf-pms), accessed November 23, 2025, https://www.lpi.usra.edu/meetings/lpsc2007/pdf/1654.pdf
2.  HEPA Filter Testing for Life Support Systems on Artemis Lunar Missions, accessed November 23, 2025, https://ttu-ir.tdl.org/bitstreams/01236268-2dc8-46ab-a3fe-6d9d5cbd9797/download
3.  Effects of gravity on cohesive behavior of fine powders: Implications for processing Lunar regolith - ResearchGate, accessed November 23, 2025, https://www.researchgate.net/publication/225955959_Effects_of_gravity_on_cohesive_behavior_of_fine_powders_Implications_for_processing_Lunar_regolith
4.  How do you properly orient your filters? Explore our Filters Guide - Idex-hs.com, accessed November 23, 2025, https://www.idex-hs.com/news-events/stories-and-features/detail/orientation-of-filters
5.  Corkscrew Filter Extracts Liquid From Air Charge - NASA Technology Transfer Program, accessed November 23, 2025, https://technology.nasa.gov/patent/MSC-TOPS-118
6.  Corkscrew Filter Extracts Liquid from Air Charge - Tech Briefs, accessed November 23, 2025, https://www.techbriefs.com/component/content/article/49236-msc-tops-118
7.  filtration - NASA Technology Transfer Program, accessed November 23, 2025, https://technology.nasa.gov/tags/filtration
8.  The Physics and Manipulation of Dean Vortices in Single- and Two-Phase Flow in Curved Microchannels: A Review - PMC, accessed November 23, 2025, https://pmc.ncbi.nlm.nih.gov/articles/PMC10745399/
9.  Numerical investigation of Dean vortex evolution in turbulent flow through 90° pipe bends, accessed November 23, 2025, https://www.frontiersin.org/journals/mechanical-engineering/articles/10.3389/fmech.2025.1405148/full
10.  Enhancing particle focusing: a comparative experimental study of modified square wave and square wave microchannels in lift and Dean vortex regimes - PubMed Central, accessed November 23, 2025, https://pmc.ncbi.nlm.nih.gov/articles/PMC10834497/
11.  Lab on a rod: Size-based particle separation and sorting in a helical channel - PMC, accessed November 23, 2025, https://pmc.ncbi.nlm.nih.gov/articles/PMC7661098/
12.  A Novel Centrifugal Filtration Device - MDPI, accessed November 23, 2025, https://www.mdpi.com/2297-8739/9/5/129
13.  In a curved channel two counter rotating Dean vortices (secondary flow)... - ResearchGate, accessed November 23, 2025, https://www.researchgate.net/figure/n-a-curved-channel-two-counter-rotating-Dean-vortices-secondary-flow-develop_fig1_233951453
14.  Size Matters: Crystal Size Analysis for the Louisiana Sugar Industry - LSU AgCenter, accessed November 23, 2025, https://www.lsuagcenter.com/profiles/lbenedict/articles/page1491324916020
15.  An Engineering Guide to Lunar Geotechnical Properties - NASA Technical Reports Server, accessed November 23, 2025, https://ntrs.nasa.gov/api/citations/20220014634/downloads/Final%20IEEE%20paper%20formatted%20footnote%20added.pdf
16.  Characterizing Detailed Grain Shape and Size Distribution Properties of Lunar Regolith, accessed November 23, 2025, https://ntrs.nasa.gov/citations/20210026714
17.  Particle Size Distribution of Lunar Soil - ResearchGate, accessed November 23, 2025, https://www.researchgate.net/publication/271358087_Particle_Size_Distribution_of_Lunar_Soil
18.  Bulk Density Guide – Understanding Material Weight & Flow, accessed November 23, 2025, https://www.bpsvibes.com/bulk-density-guide
19.  Exploration Science Projects | Lunar Regolith Simulants | JSC-1/1A - NASA • ARES, accessed November 23, 2025, https://ares.jsc.nasa.gov/projects/simulants/jsc-1-1a.html
20.  2021 Lunar Simulant Assessment, accessed November 23, 2025, https://lsic.jhuapl.edu/Our-Work/Working-Groups/files/Lunar-Simulants/2021%20Lunar%20Simulant%20Assessment_final.pdf
21.  Continuous inertial focusing, ordering, and separation of particles in microchannels - PNAS, accessed November 23, 2025, https://www.pnas.org/doi/10.1073/pnas.0704958104
22.  Computational and Experimental Analysis of Axial Flow Cyclone Used for Intake Air Filtration in Internal Combustion Engines - MDPI, accessed November 23, 2025, https://www.mdpi.com/1996-1073/14/8/2285
23.  Simulation of Helical-Baffle Inlet Structure Cyclone Separator - MDPI, accessed November 23, 2025, https://www.mdpi.com/2297-8739/12/6/166
24.  Lunar Dust Mitigation: A Guide and Reference - NASA Technical Reports Server, accessed November 23, 2025, https://ntrs.nasa.gov/api/citations/20220018746/downloads/TP-20220018746.pdf
25.  Modeling of electrostatic and contact interaction between low-velocity lunar dust and spacecraft | EurekAlert!, accessed November 23, 2025, https://www.eurekalert.org/news-releases/1106261
26.  Forced Triboelectrification of Fine Powders in Particle Wall Collisions - Publikationsserver der TU Clausthal, accessed November 23, 2025, https://dokumente.ub.tu-clausthal.de/servlets/MCRFileNodeServlet/clausthal_derivate_00001854/minerals-12-00132.pdf
27.  2022 Lunar Simulant Assessment, accessed November 23, 2025, https://lsic.jhuapl.edu/Our-Work/Working-Groups/files/Lunar-Simulants/2022%20Lunar%20Simulants%20Assessment%20Final.pdf
28.  Multi-Stage Filtration System | T2 Portal - NASA Technology Transfer Program, accessed November 23, 2025, https://technology.nasa.gov/patent/lew-tops-93
29.  Fine particle removal from gas stream using a helical-duct dust concentrator: Numerical study | Request PDF - ResearchGate, accessed November 23, 2025, https://www.researchgate.net/publication/333605900_Fine_particle_removal_from_gas_stream_using_a_helical-duct_dust_concentrator_Numerical_study
30.  Additively manufactured multiplexed inertial coalescence filters (Journal Article) | OSTI.GOV, accessed November 23, 2025, https://www.osti.gov/pages/biblio/1981758
31.  Effect of Inlet Air Volumetric Flow Rate on the Performance of a Two-Stage Cyclone Separator - PubMed Central, accessed November 23, 2025, https://pmc.ncbi.nlm.nih.gov/articles/PMC6644756/
32.  Understanding Industrial Cyclone Separators: Engineered for Efficient Particle Removal, accessed November 23, 2025, https://www.cecoenviro.com/understanding-industrial-cyclone-separators-engineered-for-efficient-particle-removal/
33.  Hydrodynamic mechanisms of cell and particle trapping in microfluidics - PubMed Central, accessed November 23, 2025, https://pmc.ncbi.nlm.nih.gov/articles/PMC3631262/

---
*End of Document*

## Documentation TODOs

The following figures require visual assets (screenshots or renders) that cannot be generated via Mermaid diagrams:

*   **Figure 3:** Velocity streamlines through the helical channel (OpenFOAM Output) (Section 5.2) - *Completed via PyVista post-processing pipeline.*
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

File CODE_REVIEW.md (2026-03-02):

# Code Review & Optimization Plan

This document summarizes the findings from a comprehensive review of the OpenAuto-CFD Framework (specifically focusing on the Corkscrew Filter validation study). It addresses OpenFOAM CFD stability, OpenSCAD geometry generation, and the AI-driven optimization loop. It also outlines a detailed execution plan to resolve the identified issues.

## 1. Code Review Summary

### A. CFD Stability & OpenFOAM Architecture
The project currently uses `simpleFoam` (steady-state incompressible) to resolve the flow field, followed by `icoUncoupledKinematicParcelFoam` (transient, one-way coupled) for particle tracking. This approach presents several stability challenges:

*   **The "Frozen Turbulence" Hack:** In `optimizer/foam_driver.py`, turbulence fields (`k`, `epsilon`, `omega`, `nut`) are aggressively frozen to `1e-8` right before particle tracking to prevent `SIGFPE` (math explosions) when using the `stochasticDispersionRAS` model. This indicates the steady-state `simpleFoam` run is not producing physically bounded or fully converged turbulence fields, especially near the walls or in vortex cores. Freezing these fields effectively disables the physical effect of turbulent dispersion.
*   **Physics Mismatch:** The inertial separator relies on strong, swirling, anisotropic flows (Dean vortices). Standard isotropic turbulence models, like the default `kOmegaSST` typically paired with `simpleFoam`, struggle to accurately predict turbulence in these high-swirl conditions, leading to unphysical velocity profiles that impact particle tracking accuracy.
*   **Particle Tracking Brittleness:** `icoUncoupledKinematicParcelFoam` is brittle when flow fields are imperfect. If a particle enters a boundary layer cell with an irregular velocity vector (e.g., if meshing failed to add layers), it can become trapped, bounce infinitely, or accelerate to infinity, causing solver crashes.

### B. Geometry Generation & Meshing (`snappyHexMesh` & OpenSCAD)
The pipeline generates STLs via OpenSCAD (often via WASM) and feeds them into `snappyHexMesh`, a common source of edge cases.

*   **CGAL Precondition Violations:** `openscad-wasm` frequently throws CGAL errors when boolean operations result in coincident faces, zero-thickness walls, or non-manifold edges. For example, the AI might suggest a `helix_profile_radius` matching the `helix_path_radius`, creating a zero-thickness line at the center axis. Constraints are defined but not physically enforced before passing to OpenSCAD.
*   **The `add_layers` Fallback Loop:** `foam_driver.py` includes an "Auto-Fallback" that disables boundary layers (`addLayers false;`) if `snappyHexMesh` fails. While this keeps the pipeline moving, it compromises CFD accuracy. The boundary layer is critical for particle-wall interactions (stick vs. bounce). Disabling it evaluates an inaccurate physical system.
*   **STL Quality Sensitivity:** `snappyHexMesh` is sensitive to poor-quality STLs (intersecting triangles, gaps). Malformed STLs from OpenSCAD boolean issues cause `snappyHexMesh` to fail or create poor meshes that crash the solver.
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

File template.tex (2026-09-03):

\documentclass[twocolumn]{article}
\usepackage{graphicx}
\usepackage{amsmath}
\usepackage{hyperref}
\usepackage[utf8]{inputenc}
\usepackage{geometry}
\geometry{a4paper, margin=1in}

\providecommand{\tightlist}{%
  \setlength{\itemsep}{0pt}\setlength{\parskip}{0pt}}

$if(highlighting-macros)$
$highlighting-macros$
$endif$
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

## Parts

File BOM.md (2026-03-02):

# Bill of Materials

This document lists the required components to build the Corkscrew Filter used in the OpenAuto-CFD validation study.

## Off-the-Shelf Components

| Item | Description | Link |
| --- | --- | --- |
| O-Ring | 30mm OD, 27mm ID, 1.5mm Width | [Amazon](https://www.amazon.com/dp/B07D24HPPW) |
| Main Tube | Clear, 1 3/16" (30mm) ID, 1 1/4" (32mm) OD | [Amazon](https://www.amazon.com/dp/B0DK1CNVDQ) |
| Heat Shrink Coupling (Optional) | 1-1/2" (40mm) | [Amazon](https://www.amazon.com/dp/B0B618769H) |
| Vacuum Hose (Example) | 1.15" ID, 1.34" OD | - |

## 3D Printed Components

The following parameters in `corkscrew filter.scad` should be used to generate the 3D printable parts that match the components listed above.

### Main Parameters
```openscad
num_bins = 3;
number_of_complete_revolutions = 12;
screw_OD_mm = 1.8;
screw_ID_mm = 1;
scale_ratio = 1.4;
```

### Tube Filter Parameters
```openscad
tube_od_mm = 32;
tube_wall_mm = 1;
insert_length_mm = 350/2;
oring_cross_section_mm = 1.5;
spacer_height_mm = 5;
adapter_hose_id_mm = 30;
support_rib_thickness_mm = 1.5;
support_density = 4;
flange_od = 20;
flange_height = 5;
```

### Tolerances & Fit
These values may need to be adjusted based on your specific 3D printer's calibration.
```openscad
tolerance_tube_fit = 0.2;
tolerance_socket_fit = 0.4;
tolerance_channel = 0.1;
```

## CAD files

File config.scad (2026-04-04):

// =============================================================================
// --- Parametric Corkscrew Filter Configuration ---
// =============================================================================
// This file contains all the user-configurable parameters for the filter.
// Modify the values here to change the generated model.

// =============================================================================
// --- A. High-Level Control Panel ---
// =============================================================================

// --- 1. Model Selection ---
// This variable controls which component is rendered.
part_options = ["modular_filter_assembly", "hex_array_filter", "single_cell_filter", "hose_adapter_cap", "flat_end_screw", "filter_holder", "custom_coupling", "inlet_cap", "outlet_cap", "cfd_wall"];
// We use is_undef to prevent overwriting if this file is included after variables are set.
default_part_to_generate = part_options[0];

// --- 2. Feature Flags ---
// These flags toggle optional features on the selected model.

// --- Modular Filter & Flat End Screw Features ---
inlet_options = ["none", "threaded", "pressfit", "barb"];
inlet_type = inlet_options[0];              // Inlet style for the end spacers of the modular filter. ["none", "threaded", "barb"]
GENERATE_CFD_VOLUME = false;     // If true, generates the negative space (fluid volume) for CFD analysis instead of the solid part.
ADD_HELICAL_SUPPORT = true;      // If true, adds a lattice-like support structure between the spacers for rigidity.

// --- Hex/Single Cell Features ---
slit_options = ["none", "simple", "ramped"];
slit_type = slit_options[1];            // Defines the type of slit cut into the helical ramps. ["none", "simple", "ramped"]
ADD_OUTER_O_RINGS = true;        // If true, adds O-Ring grooves to the outer hexagonal casing.
ADD_DEBRIS_EXIT_CHANNELS = true; // NEW: If true, cuts channels for debris to exit the hex array frame.

// --- Visual/Debug Options ---
SHOW_O_RINGS = true;             // If true, renders red O-rings in their grooves for visualization.
SHOW_TUBE = true;                // If true, renders a translucent tube around the filter for visualization.
USE_TRANSLUCENCY = true;        // If true, makes certain parts semi-transparent to see internal geometry.
CUT_FOR_VISIBILITY = false;      // If true, cuts the model in half (removes Y>0) to allow inspection of internal geometry.

// =============================================================================
// --- B. Model Parameters ---
// =============================================================================

// --- General & Precision ---
_requested_high_res_fn = is_undef(high_res_fn) ? 200 : high_res_fn; // Fragment resolution for final renders ($fn). Higher values create smoother curves.
if (_requested_high_res_fn > 120) {
    echo("WARNING: high_res_fn capped at 120 for performance stability in WASM environment.");
}
_actual_high_res_fn = min(_requested_high_res_fn, 120); // Cap resolution to prevent timeouts in WASM environment
low_res_fn = is_undef(low_res_fn) ? 10 : low_res_fn;   // Fragment resolution for previews. Lower values provide faster previews.
$fn = $preview ? low_res_fn : _actual_high_res_fn; // OpenSCAD automatically uses the appropriate value.

// --- Tube & Main Assembly Parameters ---
tube_od_mm = 32;                 // The outer diameter of the tube the filter assembly will be inserted into.
tube_wall_mm = 1;                // The wall thickness of the tube. Used to calculate the inner diameter.
tube_length_override = 0;        // Custom length for the visualized tube (0 = auto/match component).
insert_length_mm = 50 ;      // The total length of the filter insert from end to end.
num_bins = 3;                    // The number of separate helical screw segments in the modular assembly.
cfd_shape = "circle";            // Shape of the fluid domain for CFD ["circle", "square", "hex"].

// --- Helical Screw Parameters ---
number_of_complete_revolutions = 1; // How many full 360-degree turns the screw makes over its total length.
helix_path_radius_mm = 1.8;      // The radius of the helical path, measured from the central axis to the center of the screw's profile.
helix_profile_radius_mm = 1.8;   // The radius of the circular cross-section of the solid screw itself.
helix_void_profile_radius_mm = 1; // The radius of the circular cross-section of the channel (the void) inside the screw.
helix_profile_scale_ratio = 1.4; // Stretches the screw's circular profile along one axis to create an ellipse, increasing surface area.

// --- Spacer & O-Ring Parameters ---
spacer_height_mm = 5;            // The axial height of each spacer disk.
oring_cross_section_mm = 1.5;    // The diameter of the O-ring cord.

// --- Helical Support Parameters ---
support_rib_thickness_mm = 2.5;  // The diameter of the individual struts that make up the helical support.
support_revolutions = 4;         // The number of revolutions the support struts make. (Note: This is not currently used, twist is derived from the main helix).
support_density = 4;             // The number of support bundles distributed around the circumference.

// --- Hose Adapter Cap Parameters ---
adapter_hose_id_mm = 30;         // The inner diameter of the hose that will connect to the end cap adapter.
flange_od = 20;                  // The outer diameter of the flange on the hose adapter.
flange_height = 5;               // The height of the flange on the hose adapter.
ADAPTER_AXIAL_SEAL = true;      // If true, uses an axial (face) seal with a cup for the tube. If false, uses a radial seal.

// --- Inlet Parameters (for Modular Filter) ---
// Threaded Inlet
threaded_inlet_id_mm = 4;        // The outer diameter of the threaded portion of the inlet.
threaded_inlet_flange_od = threaded_inlet_id_mm + 4; // The diameter of the flange at the base of the threaded inlet.
threaded_inlet_height = 10;      // The height of the threaded inlet.
// Barb Inlet
barb_inlet_id_mm = 4;            // The inner diameter of the hose barb.
barb_inlet_count = 3;            // The number of individual barbs on the fitting.
barb_inlet_flange_od = barb_inlet_id_mm + 4; // The diameter of the flange at the base of the barb inlet.

// --- Filter Holder Parameters ---
filter_holder_cartridge_od = 10;
filter_holder_cartridge_thread_inner = false;
filter_holder_cartridge_thread_outer = false;
filter_holder_tube_thread_inner = false;
filter_holder_tube_thread_outer = true;
filter_holder_cartridge_wall_height = 10;
filter_holder_cartridge_offset = 0;

// --- Custom Coupling Parameters ---
// These are defaults, usually overridden by including a specific config file.
custom_coupling_type = is_undef(custom_coupling_type) ? "none" : custom_coupling_type;
barb_input_diameter = 5;
barb_output_diameter = 6.5;
barb_wall_thickness = 1;
barb_length = 2;
barb_count = 4;
barb_swell = 1;
coupling_lip_height = 2.4;
coupling_lip_width = 16.9;
coupling_outer_coupling_od = 14.91;
coupling_outer_coupling_height = 10;
coupling_inset_height = 23.5;
coupling_inset_width = 30.3;
coupling_inner_inlet = 29;
coupling_inner_height = 2.37;
coupling_inner_outlet = 5.2;


// --- Hex Array & Single Cell Filter Parameters ---
cell_diameter = 10;              // The outer diameter of the helical filter within a single cell.
cell_length = 100;               // The total Z-height (length) of a filter cell.
num_helices = 1;                 // The number of interleaved helical ramps (e.g., like a multi-start thread).
ramp_width_degrees = 20;         // The angular width of a single helical ramp.
total_revolutions = 8;           // The number of full turns a helix makes over the `cell_length`.
num_stages = 3;                  // The number of stacked, separated helical segments within a single cell. [1, 2, or 3]
hex_array_layers = 1;            // The number of hexagonal rings around the central cell (0=1 cell, 1=7 cells, 2=19 cells).
outer_casing_wall_mm = 3;        // The wall thickness of the hexagonal casing for the array.

// --- Slit Parameters ---
slit_ramp_length_mm = 5;         // The length of the ramped portion of a slit (for "ramped" `slit_type`).
slit_open_length_mm = 5;         // The length of the fully open portion of a slit.
slit_width_mm = 2;               // The width of the slit opening.
slit_depth_mm = 2;               // The depth of the slit cut into the ramp.
slit_axial_length_mm = 1.5;      // The height (Z-axis) of the slit cut for CorkscrewSlitKnife.
slit_chamfer_height = 0.5;       // The height of the chamfer on the leading edge of the slit knife.
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

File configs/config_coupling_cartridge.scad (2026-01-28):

// =============================================================================
// --- Cartridge Coupling Configuration ---
// =============================================================================

// 1. Load Defaults
include <../config.scad>

// 2. Override Parameters
part_to_generate = "custom_coupling";
custom_coupling_type = "cartridge";

// --- Barb Parameters ---
barb_input_diameter = 5;
barb_output_diameter = 6.5;
barb_wall_thickness = 1;
barb_length = 2;
barb_count = 4;
barb_swell = 1;

// --- Coupling Geometry ---
coupling_lip_height = 2.4;
coupling_lip_width = 16.9;
coupling_outer_coupling_od = 14.91;
coupling_outer_coupling_height = 10;
coupling_inset_height = 23.5;
coupling_inset_width = 30.3126; // approx 30.312598673823808020208399115883
coupling_inner_inlet = 29;
coupling_inner_height = 2.37;
coupling_inner_outlet = 5.2;

// 3. Generate Model
include <../corkscrew.scad>

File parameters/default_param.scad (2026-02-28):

// Corkscrew Filter - Default Configuration File
//
// To create a new configuration, copy this file, rename it,
// and change the `config_file` variable in `corkscrew filter.scad`
// to point to your new file.

// --- Main Parameters ---
num_bins = 1;
// number_of_complete_revolutions = 3;
// screw_OD_mm = 1.8;
// screw_ID_mm = 1;
// scale_ratio = 1.4;

// --- NEW PARAMETERS for Tube Filter ---
tube_od_mm = 32;
tube_wall_mm = 1;


// Case 1
insert_length_mm = (350/2)/6;


// Assuming OD/2 = profile_radius = path_radius (so screw touches center)
// And ID/2 = void_profile_radius
helix_profile_radius_mm = 1.0;
helix_path_radius_mm = 1.1; // +0.1 to avoid touching center
helix_void_profile_radius_mm = 0.5;

// Simplify to avoid CGAL errors
slit_type = "none";
ADD_HELICAL_SUPPORT = false;
inlet_type = "none";

// Case 2
//insert_length_mm = 100;
//screw_OD_mm = 5;
//screw_ID_mm = 3.5;

hex_spacing = 5;


oring_cross_section_mm = 1.5;
spacer_height_mm = 5;
adapter_hose_id_mm = 30;
support_rib_thickness_mm = 1.5;
support_density = 4;
flange_od = 20;
flange_height = 5;

// --- Tolerances & Fit ---
tolerance_tube_fit = 0.2;
tolerance_socket_fit = 0.4;
tolerance_channel = 0.1;


// Rob's variables. These have not been coordinated with Lawrence's above yet.



// use <BarbGenerator-v3.scad>;


// Params (mm), degrees 
number_of_complete_revolutions = 1*num_bins;
// WARNING! Trying to reduce this to one bin seemed to make the slit go away


cell_wall_mm = 1.4;
barb_input_diameter = 2;
barb_output_diameter = 5;
barb_wall_thickness = 1;

// The slit_axial_open_length_mm is the "length",
// in an axial sense of the 
slit_axial_open_length_mm = 1;
// slit_axial_length_mm = cell_wall_mm + slit_axial_open_length_mm;
slit_axial_length_mm = 1.5;
slit_chamfer_height = 0.5;

// The "slit_knife" is "radial" in the since that it cuts
// a pie-slice shaped slit into the wall of the helix.
// The wider the angle, the greater the slit. 180 would
// be half the slit. I suggest this be limited to 45 degrees.
slit_knife_angle = 45;
FN_RES = 60;

screw_center_separation_mm = 3;


scale_ratio = 1.4; // This is used to acheive a more circular air path

bin_wall_thickness_mm = 1;

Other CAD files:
configs/config_coupling_sandblaster.scad
BarbGenerator-v3.scad
ThirstyCorkscrew.scad
ThirstyCorkscrew_3Bin_Scaled.scad
barb_coupling.scad
barb_coupling_cartridge.scad
barb_coupling_sandblaster.scad
configs/filter_holder.scad
configs/flat_end_screw.scad
configs/hex_array_filter.scad
configs/hose_adapter_cap.scad
configs/modular_filter_assembly.scad
configs/single_cell_filter.scad
configs/threaded_modular_filter_pipe.scad
corkscrew filter in progress.scad
corkscrew filter.scad
corkscrew.scad
corkscrew_filter_merge.scad
corkscrew_filter_v22.scad
corkscrew_filter_v40.scad
cyclone_filter_manifold.scad
dipole_antenna.scad
legacy/openscad/configs/config_coupling_sandblaster.scad
legacy/openscad/configs/filter_holder.scad
legacy/openscad/configs/flat_end_screw.scad
legacy/openscad/configs/hex_array_filter.scad
legacy/openscad/configs/hose_adapter_cap.scad
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

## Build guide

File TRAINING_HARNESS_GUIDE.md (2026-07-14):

# LLM Fine-Tuning Training Harness Guide

To bridge the gap between foundational physics knowledge and specific, continuous-simulation design loops (such as OpenFOAM CFD, openEMS, or FEA), this project includes a robust, solver-agnostic **LLM Training Harness**.

The training harness allows you to extract past trajectories of optimization parameters and programmatically compile them into rich instruction-tuning datasets. These datasets include synthesized, physics-informed **Chain-of-Thought (CoT)** reasoning blocks that instill Specialized Parameter-Selection Intuition into any open-source or commercial model.

---

## Architecture Overview

Rather than training the model on static, isolated configurations, the harness models the optimization loop as a sequence of **State Transitions** ($Run_N \to Run_{N+1}$):

```
       [State N Prompt]
  +------------------------+
  | - History of Runs      |
  | - Last Run Parameters  |       [Fine-Tuned LLM]
  | - Last Run Metrics/Err | ------------+
  +------------------------+             |
              |                          v
              v                [Next Design Decision]
    [Synthesized Physics CoT] +-----------------------+
   "Since the previous run    | - Next Parameters     |
    failed with meshing_failed| - Stop Signal (bool)  |
    due to cramped channels,  +-----------------------+
    we widen path_radius..."
```

---

## 1. Quick Start

The training harness lives at `optimizer/generate_training_data.py`.

### Generate OpenAI Chat Format (SFT)
Export consecutive steps of successful runs or troubleshooting runs in the standard OpenAI Messages JSONL format:
```bash
python optimizer/generate_training_data.py configs/corkscrew_config.yaml \
    --log-file optimization_log.jsonl \
    --output-file sft_chat_data.jsonl \
    --format openai \
    --filter all
```

### Generate Direct Preference Optimization (DPO) Pairs
Export preferred vs. non-preferred (failed or worse performing) parameter transitions from the exact same simulation state:
```bash
python optimizer/generate_training_data.py configs/corkscrew_config.yaml \
    --log-file optimization_log.jsonl \
    --output-file dpo_data.jsonl \
    --format dpo
```

---

## 2. CLI Options Reference

| Argument | Type | Default | Description |
| :--- | :--- | :--- | :--- |
| `config_file` | `str` | *Required* | Path to the problem definition YAML file (e.g., `configs/corkscrew_config.yaml`). Specifies search parameters, bounds, optimization goals, and constraints. |
| `--log-file` | `str` | `optimization_log.jsonl` | Path to the optimization history log file. |
| `--output-file`| `str` | `training_data.jsonl` | Target output path for the exported training data. |
| `--format` | `choice`| `openai` | Target dataset format. Options: `openai` (chat messages), `alpaca` (instruction-input-output), `dpo` (chosen/rejected pairs). |
| `--filter` | `choice`| `all` | Sourcing/filtering strategy. Options:<br>• `all`: Keep all continuous steps.<br>• `success`: Keep transitions where the score improved.<br>• `error-correction`: Keep steps where $Run_N$ failed and $Run_{N+1}$ recovered/fixed it. |

---

## 3. Training Formats & Datasets

### A. OpenAI Chat Format (`--format openai`)
Ideal for supervised fine-tuning (SFT) of modern chat models (e.g., LLaMA, Qwen, Mistral) using popular libraries like Axolotl, Unsloth, or Hugging Face SFTTrainer.
```json
{
  "messages": [
    { "role": "system", "content": "...[YAML Goals & Constraints]..." },
    { "role": "user", "content": "HISTORY OF RUNS:\n... [Previous Parameters & Metrics] ...\nLATEST RUN:\n... [Preceding Step Details] ..." },
    { "role": "assistant", "content": "{\n  \"reasoning\": \"The previous run completed successfully. Let's inspect the target objective 'separation_efficiency'. Modify 'helix_path_radius_mm' from 1.8 to 2.2...\",\n  \"stop_optimization\": false,\n  \"parameters\": { \"helix_path_radius_mm\": 2.2, \"helix_profile_radius_mm\": 1.7 }\n}" }
  ]
}
```

### B. Alpaca Format (`--format alpaca`)
Widely used for instruct-tuning foundational models.
```json
{
  "instruction": "... [System Prompt / YAML Guidelines] ...",
  "input": "... [History & Preceding Run Metrics] ...",
  "output": "{\n  \"reasoning\": \"... [Physics Chain-of-Thought] ...\",\n  \"parameters\": { ... }\n}"
}
```

### C. Direct Preference Optimization (`--format dpo`)
An extremely powerful format to teach models to **avoid unstable physics and prioritize manifold geometries** by showing a preferred versus a rejected action from the same state.
```json
{
  "prompt": "<|system|>\n... [Constraints] ...\n<|user|>\n... [History & Last Run Result] ...",
  "chosen": "{\n  \"reasoning\": \"... [Physics reasoning to resolve the error] ...\",\n  \"parameters\": { \"helix_path_radius_mm\": 2.5, \"helix_profile_radius_mm\": 1.5 }\n}",
  "rejected": "{\n  \"reasoning\": \"We will set parameters without considering geometric constraints...\",\n  \"parameters\": { \"helix_profile_radius_mm\": 2.5, \"helix_path_radius_mm\": 2.5 }\n}"
}
```

---

## 4. How the Physics Reasoning Engine Works

To keep the model from overfitting to raw numbers, the harness programmatically synthesizes a **physics-informed engineering Chain-of-Thought (CoT)**:

1. **State Diagnostics**: If the previous run crashed (e.g., `geometry_invalid_volume` or `meshing_failed`), it automatically synthesizes reasoning targeting that specific error:
   - *Example*: `"The geometry generated a non-manifold shape with zero or negative volume... to resolve boundary non-orthogonality/cramping, we will increase helix_path_radius_mm..."*
2. **Delta Analysis**: It identifies which parameters changed between step $N$ and step $N+1$ and explains the fluid dynamics / EM trade-offs associated with those changes:
   - *Radius decrease*: Explained as narrowing the channel to increase local flow velocities and boost centrifugal separation forces.
   - *Pitch/Revolutions increase*: Explained as lengthening particle residence time for additional centrifugal separation cycles.
3. **Intent Formulation**: It articulates a final engineering trade-off balance statement so that the fine-tuned model learns "the why" behind the adjustments.

---

## 5. Machine & Software Requirements

When choosing hardware and setting up the training stack for model fine-tuning (SFT & DPO), you need to match your compute resources to the model size and training precision.

### A. Hardware Recommendations (Based on Model Size)

We recommend targeting **8B to 14B parameter models** (e.g., LLaMA-3-8B or Qwen-2.5-14B) as they provide an outstanding balance between reasoning capabilities and fast inference/training on mainstream enterprise hardware.

| Model Size | Training Strategy | Minimum GPU Hardware | Recommended GPU Hardware | VRAM Needed |
| :--- | :--- | :--- | :--- | :--- |
| **8B Parameters** (e.g., LLaMA-3) | **QLoRA (4-bit)** | 1x NVIDIA T4 / L4 | 1x RTX 3090 / 4090 | ~16 GB - 24 GB |
| **8B Parameters** | **LoRA (16-bit BF16)** | 1x RTX 3090 / 4090 | 1x NVIDIA A10G / A30 | ~24 GB - 32 GB |
| **8B Parameters** | **Full Fine-Tuning** | 1x A100 (40GB) | 1x H100 (80GB) | ~40 GB - 80 GB |
| **14B Parameters** (e.g., Qwen-2.5) | **QLoRA (4-bit)** | 1x RTX 3090 / 4090 | 1x NVIDIA L4 / A10G | ~24 GB |
| **14B Parameters** | **LoRA (16-bit BF16)** | 1x A10G (24GB) | 1x A100 (40GB / 80GB) | ~32 GB - 40 GB |
| **14B Parameters** | **Full Fine-Tuning** | 2x A100 (80GB) | 4x A100 / H100 (80GB) | ~160 GB+ |
| **70B Parameters** (e.g., LLaMA-3-70B) | **QLoRA (4-bit)** | 1x A100 (80GB) | 2x RTX 3090/4090 (with Deepspeed) | ~48 GB - 80 GB |
| **70B Parameters** | **LoRA (16-bit BF16)** | 2x A100 (80GB) | 4x A100 (80GB) | ~120 GB+ |

#### Crucial Hardware Best Practices:
* **Storage**: Fast SSD / NVMe (at least 100 GB free space) is critical to prevent I/O bottlenecks when loading models and periodically saving checkpoints.
* **System RAM**: Standard rules-of-thumb require system RAM to be **at least 2x the VRAM size** of your configuration to avoid Out-of-Memory (OOM) failures during tokenization, logging, and dataset caching.
* **Bfloat16 Support**: BF16 support is highly recommended. Ensure you use Ampere or newer architectures (RTX 30/40 series, A10, A100, L4, H100) to prevent gradient underflow/overflow stability issues common with older FP16 training on Volta or Pascal.

---

### B. Software Stack Guidelines

To implement local fine-tuning within your cluster, use the following production-tested software stack:

1. **Operating System**:
   - Native **Linux (Ubuntu 22.04 LTS / 24.04 LTS)** or **WSL2** for Windows environments. (Avoid bare Windows setups as triton, deepspeed, and flash-attention are notoriously difficult to compile natively on Windows).
2. **CUDA & GPU Driver Stack**:
   - NVIDIA Driver `v535+` or `v550+`.
   - CUDA Toolkit `12.1` or `12.4` (ensure your PyTorch, Deepspeed, and Flash-Attention compiles match the matching toolkit version).
3. **Training & Fine-Tuning Libraries**:
   - **Axolotl** (Highly recommended for configuration-driven LoRA, QLoRA, SFT, and DPO training).
   - **Unsloth** (Extremely fast; reduces training time and memory usage by up to 80% on single-GPU SFT setups).
   - **Hugging Face TRL (Transformer Reinforcement Learning)**: Standard script runner utilizing `SFTTrainer` and `DPOTrainer`.
4. **Acceleration Libraries**:
   - **Flash-Attention 2**: Essential for training with larger contexts ($4096+$ tokens) to reduce attention computational complexity from quadratic to linear.
   - **DeepSpeed (ZeRO-2 or ZeRO-3)**: Required for distributed multi-GPU training or partitioning large model parameters/gradients across memory.

---

## 6. Fine-Tuning Recipe (Axolotl / Hugging Face)

Once you've exported your datasets, you can launch a local fine-tuning job.

### Sample SFT Configuration (Axolotl `config.yml` snippet)
```yaml
base_model: Qwen/Qwen2.5-14B-Instruct
model_type: AutoModelForCausalLM
tokenizer_type: AutoTokenizer

datasets:
  - path: sft_chat_data.jsonl
    type: sharegpt  # compatible with openai chat format
    conversation: qwen-2.5

chat_template: qwen_2_5
output_dir: ./fine_tuned_physics_model

sequence_len: 4096
adapter: lora
lora_r: 16
lora_alpha: 32
lora_dropout: 0.05
lora_target_modules:
  - q_proj
  - k_proj
  - v_proj
  - o_proj
  - gate_proj
  - up_proj
  - down_proj

gradient_accumulation_steps: 4
micro_batch_size: 2
num_epochs: 3
learning_rate: 0.0002
optimizer: adamw_torch
lr_scheduler: cosine
```

Launch Axolotl:
```bash
accelerate launch -m axolotl.cli.train config.yml
```

---

## 7. Testing Your Fine-Tuned Model

After training, export your model weights and place them on your local Nomad, Docker, or local machine. You can activate the model in your optimization loop by pointing to it via environment variables:

```bash
# Configure the optimizer script to utilize your local/custom Ollama or OpenAI compatible model:
export OLLAMA_HOST="http://localhost:11434"
export OLLAMA_MODEL="fine_tuned_physics_model:latest"

# Run the design loop to evaluate the new model's performance!
python optimizer/main.py configs/corkscrew_config.yaml \
    --iterations 10 \
    --case-dir corkscrewFilter
```

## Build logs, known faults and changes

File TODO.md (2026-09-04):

# Project To-Do List

This file tracks planned enhancements and future work for the OpenAuto-CFD framework and the Corkscrew Filter validation study.

## Real-Time Simulation, Model Fusion & Agentic CAD Roadmap (Completed)
- [x] **Multi-Physics Surrogate & Model Fusion:** Universal RBF surrogate supporting coupled CFD (OpenFOAM), FEA structural stress (CalculiX), and EM (openEMS) metrics with 3D spatial vector fields (`surrogate_multiphysics.py`).
- [x] **Exact Differentiable Gradients & Inverse Design:** Analytical exact RBF derivatives ($\approx 10^{-10}$ error vs finite differences) and multi-start L-BFGS-B inverse design optimizer converging in $<10\text{ ms}$ (`surrogate_gradients.py`).
- [x] **Binary GPU Buffer Streaming:** High-performance binary GPU buffer exporter (`.bin` format) for 3D field data exchange (`cfd_fea_field_io.py`).
- [x] **Asynchronous Worker Queue:** Non-blocking background simulation queue with worker pool (`async_solver_queue.py`).
- [x] **Phase 1: Real-Time Interactive WebGL Viewer (Atlas-Style Frontend):** Modern Three.js dark-mode technical HUD with 60 FPS slider scrub, particle streamline ribbons, FEA stress heatmaps, and AI inverse design button (`viewer/web/`, `viewer/server.py`, `run_viewer.py`).
- [x] **Phase 2: Multi-Fidelity Mesh Pyramid:** Kennedy & O'Hagan Co-Kriging model ($y_H = \rho y_L + \delta(x)$) with dynamic mesh resolution switching (`multifidelity_driver.py`) and a Two-Stage Active Screening Filter (`model_fusion_multifidelity.py`) delivering a $2.9\times$ compute speedup.
- [x] **Phase 3: Physics-Informed Conservation Regularizer (PINN):** Discrete Exterior Calculus Helmholtz-Hodge solenoidal projector $(D D^T) \boldsymbol{\lambda} = D \mathbf{u}$ enforcing incompressibility ($\nabla \cdot \mathbf{u} = 0$) with $100\%$ divergence elimination in $<25\text{ ms}$, plus Cauchy stress divergence equilibrium ($\nabla \cdot \boldsymbol{\sigma} \approx \mathbf{0}$) (`pinn_conservation.py`).
- [x] **Phase 4: LLM Tool-Calling Integration (Kimi K3 / Gemini CAD Agent):** Standard OpenAPI / JSON Schema function-calling specs (`predict_surrogate`, `run_inverse_design`, `check_physics_conservation`, `dispatch_simulation`, `check_simulation_status`, `generate_scad_code`), `CADAgentToolRegistry`, and `CADReasoningAgent` autonomous multi-turn reasoning loop (`cad_agent_tools.py`, `llm_agent.py`).

## build123d CAD Engine & Multi-Physics Refactor
- [x] **Pure Python CAD Engine (`build123d`):** Rewrote all project 3D models (`optimizer/cad_models.py`) into native Python `build123d` B-rep solids (corkscrew filter, dipole antenna, puck antenna, cyclone filter manifold, trace optimizer, hose adapter cap, custom couplings, and filter holders).
- [x] **Parametric 3D Filleting & Chamfering:** Added native B-rep 3D chamfering (`blade_chamfer_mm`) and filleting (`inlet_fillet_radius_mm`) to eliminate flow turbulence and stress concentrations.
- [x] **Legacy OpenSCAD Fallback:** Preserved existing OpenSCAD scripts in `legacy/openscad/` with configurable engine selection (`CadEngineFactory`).
- [x] **Direct STEP-to-Mesh Volume Pipeline (`gmsh`):** Implemented `GmshDriver` (`optimizer/gmsh_driver.py`) for direct STEP CAD B-rep volume meshing into OpenFOAM (`gmshToFoam`).
- [x] **Meshing Performance & Quality Benchmark Suite:** Created `scripts/benchmark_meshing.py` to compare SnappyHexMesh (STL surface) vs. Gmsh (STEP B-rep) on wall-clock time, peak memory footprint, cell counts, aspect ratio, non-orthogonality, and skewness.
- [x] **Self-Contained Interactive 3D WebGL Visualizer:** Implemented Three.js WebGL HTML exporter (`CadDriverBase.generate_interactive_html`) with embedded STL models for interactive 3D browser viewing.
- [x] **Automated FEA Structural Validation (`FeaDriver`):** Enhanced `FeaDriver` (`optimizer/fea_driver.py`) to evaluate von Mises stress (`max_von_mises_stress_MPa`), displacement (`max_displacement_mm`), and factor of safety (`factor_of_safety`).
- [x] **Multi-Node Worker Fault-Tolerance:** Added worker heartbeats (`record_heartbeat`) and automatic dead-worker stale job recovery (`requeue_stale_jobs`) to `job_manager.py` and `worker.py`.
- [x] **Fine-Tuning Dataset Generator Updates:** Updated `optimizer/generate_training_data.py` to synthesize Chain-of-Thought (CoT) reasoning for `build123d` parametric CAD mutations.
- [x] **Multi-Objective Pareto Optimization & World Model:** Added non-dominated Pareto front calculation and plotting (`optimizer/scoring.py`), and updated Schema surrogate transition rules (`optimizer/harness/surrogate.py`).
- [x] **1-to-1 Parity Test Suite:** Added `test/test_cad_parity.py` verifying 1-to-1 STL bounding box and volume parity (< 1.5% difference) between OpenSCAD and `build123d`.

- [x] Add the ability to make different parameter configurations based on included config files.
- [x] Refine the `CorkscrewSlitKnife` geometry to have a chamfered or ramped leading edge to improve separation efficiency.
- [x] Conduct CFD analysis to test different design parameters (slit shape, screw pitch, etc.) - *Enabled via new parameters in config.scad and optimizer/constraints.py*
- [x] Add particle tracking to the CFD simulation to visualize and quantify separation effectiveness.
- [x] Document `optimizer/` and `parameters/` directories in the README. These are core functions for simulation and parameter evaluation.
- [x] Complete refactor of barb generators into a unified, parameterized `Barb` module.
- [x] Create `FilterHolder` part (barb fitting with dual O-rings and optional threading).
- [x] Standardize coupling configurations (Cartridge, Sandblaster) into `configs/` files.

## Distributed Optimization (Git-Based)
- [x] **Data Schema:** Design a JSONL-based schema for the Job Queue/Result Log. This format should favor append-only operations to minimize merge conflicts when multiple users push results.
- [x] **Job Manager:** Implement a `JobManager` class capable of:
    - "Checking out" a specific parameter region of interest.
    - Generating a local queue of jobs derived from that region.
    - Managing the state of claimed jobs.
- [x] **Versioning Strategy:** Implement a hashing or UUID system to link specific job queues/results to the git commit hash of the codebase at the time of execution. This ensures reproducibility.
- [x] **Agent "Campaign" Mode:** Update the `LLMAgent` to support generating batch "campaigns" (multiple parameter sets) into the queue, rather than single-step iterations.
- [x] **Synchronization Workflow:** Create scripts/logic to handle the `pull` -> `claim` -> `run` -> `push` lifecycle, allowing a team to collaborate on the optimization surface asynchronously.
- [x] **CLI Region Support:** Updated `generate_campaign.py` to allow direct job generation for specific parameter regions (e.g., `--param key=min:max`) without requiring LLM assistance.

## Simulation Fidelity & Physics
- [x] **Re-enable Lagrangian Turbulence:** Remove the `_disable_turbulence` hack in `foam_driver.py`. Update `kinematicCloudProperties` to use `dispersionModel StochasticDispersionRAS;` to accurately model particle re-entrainment.
- [x] **Safeguard Wall Distances:** Add `postProcess -func wallDist` to the simulation pipeline immediately prior to particle tracking to prevent crashes when evaluating turbulent wall functions.
- [x] **Switch Integration Scheme:** Change the particle tracking integration scheme from `Euler` to `analytical` in `kinematicCloudProperties` to resolve the SIGFPE math explosion caused by explicit integration overshooting drag equilibrium on fine particles.

## Metric Extraction & Data Handling
- [x] **Implement `particleCollector`:** Inject `particleCollector` into the `cloudFunctions` dictionary to capture discrete particle fate data for individual trapping bins.
- [x] **Aggregate Patch Data:** Update `foam_driver.get_metrics()` to parse the `particleCollector` CSV/OBJ outputs. Aggregate the raw hit counts into LLM-friendly summary statistics (e.g., capture efficiency per bin).
- [x] **Ensure Face Flux (Phi):** Run `postProcess -func writePhi` automatically when preparing the transient `0` directory from steady-state results to ensure velocity interpolation works for all sub-models.

## Optimization Loop & Architecture
- [x] **Inter-Simulation Parallelization:** Refactor the optimization orchestrator (`main.py` / `worker.py`) to process LLM-generated parameter batches concurrently by spinning up multiple asynchronous OpenFOAM container instances, rather than evaluating one design at a time.
- [x] **Bug Fix:** Fixed parameter type handling in `JobManager` to correctly distinguish between ranges (tuples) and discrete choices (lists).

## Project Readiness & Review (Jan 2026)
- [x] **Comprehensive Review:** Conducted a full review of the codebase, documentation, and tests.
- [x] **Geometry Fixes:** Attempted to fix non-planar faces in `RampedKnifeShape` (triangulation) and added epsilon overlap to cutters to improve CSG stability.
- [x] **Test Reliability:** Increased timeouts for WASM-based tests (`test/regression.js` and `test/test_parameter_stls.py`) to prevent false failures on slower environments.
- [x] **Documentation:** Updated `README.md` with explicit installation/testing instructions and `TECHNICAL_REPORT.md` with notes on missing figures.
- [x] **Geometry Stability:** Resolve persistent `CGAL error: precondition violation` in `single_cell_filter.scad` and `flat_end_screw.scad` when running in `openscad-wasm`. (Native OpenSCAD may work fine). *Update: Added unit tests in `test/test_wasm_cgal_error.py` tracking this as an upstream issue in openscad-wasm handling of complex boolean extrusions.*
- [x] **Visual Assets:** Generate and insert Figure 3 (Velocity Streamlines) into `TECHNICAL_REPORT.md` using ParaView / PyVista pipeline.

## Post-Review Improvements (Code Review Action Items)
- [ ] **CFD Stability:** Investigate why `k`, `epsilon`, `omega`, and `nut` turbulence fields are blowing up in steady-state simulations, rather than freezing them to `1e-8`. Consider alternative turbulence models (e.g., RNG k-epsilon) better suited for swirling, anisotropic flows.
- [x] **Meshing Reliability:** Remove the "Auto-Fallback" mechanism that drops boundary layers (`addLayers false`) when `snappyHexMesh` fails. Boundary layers are critical for accurate particle tracking near walls. If meshing fails, the design should be rejected with explicit feedback.
- [x] **End-to-End Non-CFD Testing:** Implement a "Dry-Mesh" testing step in the optimization loop that runs `blockMesh` and `snappyHexMesh` (without running the solver) and evaluates the output of `checkMesh`. Use this to validate manufacturability and meshability before running expensive CFD simulations.
- [x] **Stricter Geometry Validation:** Enhance the Python `Validator` to check STLs for non-manifold edges and self-intersections (using `trimesh`) before attempting to mesh them in OpenFOAM.
- [x] **Hardcode Safety Margins:** In OpenSCAD modules (e.g., `assemblies.scad`), enforce minimum geometric tolerances mathematically to prevent CGAL precondition violations, regardless of LLM parameter suggestions (e.g., explicitly prevent `helix_profile_radius` from equaling `helix_path_radius`).
- [x] **Improved LLM Feedback:** Update the LLM error feedback mechanism to provide specific, geometric reasons for simulation failures (e.g., "The mesh quality check failed due to high non-orthogonality near the slit") instead of generic OpenFOAM solver crash logs.

## Electromagnetic (EM) Optimization Pipeline
- [x] **Impedance Optimization Loop:** Create a specialized configuration and scoring system to iteratively optimize PCB trace widths for target impedance using the LLM agent.
- [x] **True VTK Field Extraction:** Implement the conversion of raw HDF5 field data from openEMS to VTK format for physically accurate visualizations.
- [x] **Complex PCB Stackups:** Extend the geometry generation and drivers to support multi-layer PCB stackups, internal planes, and vias.
- [x] **Radiation Pattern Visualization:** Add support for extracting and visualizing 3D far-field radiation patterns in Blender.

## CFD Resilient Execution Engine (Post-Review Architecture)
- [ ] **Phase 1: Immediate Stability Fixes (Numerical Stability)**
    - [x] Fix `nut` invariant: Ensure `nut >= 1e-7` globally, replacing any `uniform 0` in `internalField` or fallback boundaries.
    - [x] Fix `fvSchemes`: Enforce `limited corrected 0.33` for `snGradSchemes` and `laplacianSchemes` on harsh meshes.
    - [x] Fix `fvSchemes`: Ensure bounded upwind schemes (`bounded Gauss upwind`) are used for all turbulence parameters (`k`, `epsilon`, `omega`).
    - [x] Remove wall function applications during laminar fallback to prevent solver instability.
- [x] **Phase 2: Mesh-Quality Feedback Loop**
    - [x] Implement `checkMesh` parsing to extract `Max non-orthogonality` and `Max skewness`.
    - [x] Classify mesh quality (e.g., `good`, `marginal`, `bad`).
    - [x] Dynamically adapt `fvSchemes` limiters based on mesh classification before running the solver.
- [ ] **Phase 3: Full Orchestration System**
    - [x] Implement multi-stage Retry Ladder: Try `RNG k-epsilon` -> degrade to `k-omega SST` -> fallback to `laminar`.
    - [x] Implement proactive Field Clamping: Sanitize fields to prevent them from becoming 0, NaN, or extremely small before the solver runs.

## Phase 4: Upstream Geometry & Mesh Optimization
To address the root cause of the numerical instabilities outlined in the technical report, the mesh quality must be improved at the source rather than relying solely on `foam_driver.py` workarounds.
- [x] **Optimize OpenSCAD Geometry ($fn):** Increase facet resolution (`$fn = 60` to `120`) on helical modules to prevent `snappyHexMesh` from snapping to artificial sharp edges and creating highly skewed cells.
- [x] **Eliminate Non-Manifold Geometry (Epsilon Rule):** Add tiny overlaps (e.g., `+ 0.01mm`) to cutting tools in OpenSCAD before `union()` or `difference()` operations to eliminate zero-thickness shared edges.
- [x] **Smooth Internal Corners:** Add small chamfers or fillets to the root of the corkscrew blade to smooth the 90-degree internal corner, preventing the mesher from generating severely distorted cells at the singularity.
- [ ] **Tune `snappyHexMeshDict` (Background Grid):** Lower `target_cell_size` so at least 4 to 5 base cells fit across the narrowest gap in the corkscrew channel before refinement.
- [x] **Tune `snappyHexMeshDict` (Surface Refinement):** Increase `refinementSurfaces` level for the corkscrew geometry (e.g., `level (3 4)`) to force the mesher to divide cells closer to the twisted walls.
- [ ] **Tune `snappyHexMeshDict` (Boundary Layers):** Relax `meshQualityControls` and reduce `nSurfaceLayers` while increasing `featureAngle` to prevent prism layers from colliding on tight helices, or temporarily disable `addLayers` to isolate skewness causes.
- [ ] **Tune `surfaceFeatureExtract`:** Lower `includedAngle` (e.g., to 120 or 130) to ensure the spiraling blade edges are explicitly captured.

## Codebase Cleanup and Refactoring
This section tracks necessary repository cleanup tasks to reorganize misplaced files, remove orphaned code, and improve project structure. **Important:** Every file must be carefully examined before deletion to ensure we do not introduce regressions. This codebase has extensive debug and recovery methods that are core functionality, so do not indiscriminately delete anything that says "fix/resolve/verify".

- [x] **Group 1: Investigate Test Files Outside of the `test/` Folder.**
    - Carefully review the following test files in the root directory. If they are actual tests or test utilities, move them to `test/`. If they are redundant or outdated, delete them.
    - Files to investigate: `check_tests.py`, `generalize_tests.py`, `run_cfd_test.py`, `run_cfd_test2.py`, `test_boundaries.py`, `test_fvschemes.py`, `test_fvschemes2.py`, `test_fvsolution.py`, `test_fvsolution2.py`, `test_meshing.py`, `test_nan.py`, `update_tests.py`.
- [x] **Group 2: Investigate Orphaned Plan Files.**
    - Review `plan17.md` and `plan18.md` to see if they contain any relevant unsaved documentation. Otherwise, they appear to be orphaned agent execution plans and should be removed.
- [x] **Group 3: Investigate Debug, Recovery, and One-Off Scripts.**
    - Many scripts in the root seem related to debugging or resolving specific issues (e.g., `fix_final_merge.py`, `fix_inletoutlet.py`, `fix_merge.py`, `investigate.py`, `resolve_conflicts.py`, `resolve_foam_driver.py`, `verify_fvschemes.py`, `verify_fvsolution.py`). Examine them carefully. If they are no longer needed, they can be deleted. If they still serve a purpose, consider moving them to a `scripts/` or `tools/` folder. Do not blindly delete files that are core recovery functionalities.
- [x] **Group 4: Investigate Log Files in the Root Directory.**
    - Review `.pip_install.log` and `test_meshing3.log`. If they are not needed for reference, delete them or add them to `.gitignore` and untrack them from the repository to clean up the root folder.

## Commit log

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2025-08-02 added BOM, added support helix, fixed o rings
    need to make sure helix punches through bin bulkheads
    [corkscrew filter.scad]
2025-08-07 Fix and Refactor Corkscrew Filter SCAD Script
    I have fixed several issues in the `corkscrew filter.scad` script and refactored it for clarity and correctness.
    The key changes include:
    - Replaced the flawed helical geometry generation with a correct implementation that ensures concentricity of the screw and its void.
    - Simplified and corrected the modular assembly logic to be more robust and easier to understand.
    - Restored the missing `HoseAdapterEndCap` module.
    - Improved parameterization by removing hardcoded values and redundant calculations.
    [corkscrew filter.scad]
2025-08-07 Fix: Correct Support Placement and Add Density Parameter
    This commit addresses two follow-up issues with the helical supports:
    1. A new `support_density` parameter has been added to control the number of support bundles around the filter's circumference, making the design more flexible.
    2. The placement logic for the supports has been corrected to fix an off-by-one error, ensuring all necessary segments are supported.
    [corkscrew filter.scad]
2025-08-07 Fix: Implement Global Helical Void and Correct Socket Logic
    This commit addresses two issues:
    1. A global helical cut is now applied to the entire assembly. This ensures the void passes through the spacers (bulkheads), allowing for continuous airflow.
    2. The logic for creating screw sockets in the spacers has been adjusted to prevent a socket from being created on the top-most spacer.
    [corkscrew filter.scad]
2025-08-07 Fix: Correct Helical Segment Alignment
    This commit resolves a critical bug where the helical voids were not aligned with the solid screw segments.
    The fix involves a major refactoring of the assembly logic:
    - I've removed the global `ApplyHelicalCut` in favor of a per-segment voiding approach using the `CorkscrewWithVoid` module. This is more robust and avoids synchronization issues.
    - The `ModularFilterAssembly` now calculates a single, authoritative twist rate.
    - A rotational offset is now tracked and applied to each screw and spacer segment, ensuring they are perfectly aligned to form a continuous helix.
    [corkscrew filter.scad]
2025-08-07 Fix: Implement Hybrid Assembly for Correct Voids and Alignment
    This commit implements a new hybrid assembly strategy to resolve the conflicting issues of solid bulkheads and helical alignment.
    The new approach involves:
    1. Generating all solid geometry (screws and spacers) first.
    2. Creating a perfectly aligned, but segmented, helical void. This is done by looping and creating a void piece for each solid screw piece, using the exact same positioning and rotation logic.
    3. Using a global `difference()` operation (`ApplyHelicalCut`) to subtract the segmented void from the solid assembly.
    This ensures the void is cut through the spacers (solving the bulkhead issue) and that the void is perfec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
    [corkscrew filter.scad]
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2025-08-07 Feat: Implement Continuous Twist with Correct Bulkhead Cutting
    This commit refactors the assembly to use a continuous twist model, which resolves all outstanding alignment and bulkhead issues.
    The key changes are:
    - A continuous `twist_rate` is calculated based on the total assembly length.
    - All components (screws and spacers) are rotated into position based on their absolute Z-height, ensuring perfect alignment.
    - The `CaptureSpacer` module now cuts the helical profile from its own body, ensuring the channel is clear.
    [corkscrew filter.scad]
2025-08-08 Feat: Add Master Helix Assembly Method for Robust Alignment
    This commit introduces a new, more robust method for assembling the modular filter, nicknamed the "Master Helix" method. This approach is designed to be immune to the alignment and bulkhead-void issues encountered in previous versions.
    The new `ModularFilterAssembly` works by:
    1. Generating a single "master" solid helix and "master" void helix for the entire length of the part.
    2. Constructing the final geometry by carving pieces out of these master shapes:
    - Screws are created by intersecting the master solid with cylinders.
    - Spacers are created by differencing the master solid from cylinders.
    3. The final solid is the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
    [corkscrew filter.scad]
2025-08-08 Feat: Add Parameters for Printer Tolerances
    This commit adds a new "Tolerances & Fit" section to the global parameters, allowing for easy configuration of clearances for different printers and materials.
    The following parameters were added:
    - `tolerance_tube_fit`: Controls the clearance between the filter assembly and the inner wall of the tube.
    - `tolerance_socket_fit`: Controls the clearance between the screw segments and the spacer sockets.
    All relevant modules (`Spacer`, `CaptureSpacer`, `HoseAdapterEndCap`) have been updated to use these new parameters instead of hardcoded values.
    [corkscrew filter.scad]
2025-08-09 Fix: Refactor Helix Generation for Robustness and Add Channel Tolerance
    This commit addresses a subtle alignment issue between the inner and outer helical shells.
    The changes include:
    1. The `CorkscrewSolid` and `CorkscrewVoid` modules have been refactored to use a single, unified `HelicalShape` module. This makes it architecturally impossible for their generation logic to diverge, guaranteeing concentricity.
    2. A new `tolerance_channel` parameter has been added to slightly oversize the void-cutting tool. This prevents potential CSG artifacts at the surface boundaries and ensures a clear airflow channel.
    [corkscrew filter.scad]
2025-08-09 Fix: Ensure Consistent Twist Rate in Master Helix Method
    This commit resolves a subtle bug in the "Master Helix" assembly method where the master solid and master void helices had slightly different twist rates, causing misalignment.
    The fix involves:
    1. Calculating a single authoritative `twist_rate` in degrees/mm.
    2. Using this rate to calculate the `total_twist` for the solid and void helices based on their respective lengths. This ensures the twist rate is identical.
    3. Adding a diagnostic `echo` to the `HelicalShape` module to programmatically verify that the generated profiles are concentric, as you suggested.
    [corkscrew filter.scad]
2025-08-09 Fix: Correct Master Helix Assembly via In-line Logic
    This commit fixes a critical OpenSCAD scoping issue in the "Master Helix" assembly method.
    The `Spacer` helper module was removed and its logic for creating spacers was moved directly into the `ModularFilterAssembly` loop. This ensures the helical cut from the `MasterSolidHelix` tool is performed in the correct scope, solving all alignment and bulkhead void issues.
    [corkscrew filter.scad]
2025-08-09 Fix: Add Overlap to Resolve CSG Boundary Issue
    This commit fixes a visual artifact where the top and bottom screw bins were not being rendered correctly. This was likely due to a CSG boundary condition issue where coincident faces were not being handled cleanly by the geometry engine.
    The fix involves adding a small overlap to the height of the cylinder used to intersect the screw bins from the master helix. This ensures a clean and unambiguous intersection.
    [corkscrew filter.scad]
2025-08-09 Fix: Refactor Assembly with Correct CSG Workflow
    This commit provides a major refactoring of the `ModularFilterAssembly` to resolve fundamental alignment issues caused by an incorrect CSG workflow.
    The new implementation correctly performs all CSG operations (difference, intersection) at the origin by translating the master helix tool to align with the component being shaped. The final, shaped component is then translated and rotated into its final position.
    This ensures that the screw segments, the voids in the bulkheads, and the outer helical supports are all perfectly aligned with the master helix.
    [corkscrew filter.scad]
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2025-08-31 fix: Correct for loop syntax in OpenSCAD file
    The HexArrayLayout module in corkscrew_filter_merge.scad contained
    C-style for loops, which are not valid in OpenSCAD. This caused a
    syntax error.
    This commit corrects the for loops to use the proper OpenSCAD syntax
    (e.g., `for (i = [start : end])`).
    [corkscrew_filter_merge.scad]
2025-08-31 feat: Improve documentation and fix OpenSCAD scripts
    This commit includes several improvements and bug fixes:
    - The main README.md has been completely rewritten to provide a
    comprehensive overview of the project. It now links to the
    `BOM.md` and `TODO.md` files to keep the documentation atomic,
    as requested.
    - A syntax error in `corkscrew_filter_merge.scad` has been fixed.
    The C-style `for` loops were replaced with the correct
    OpenSCAD syntax.
    - A logical bug in the `HexArrayLayout` module within
    `corkscrew_filter_merge.scad` has been fixed. The vector
    calculation for positioning elements in the hexagonal array was
    corrected, allowing the module to generate the array as in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
    [corkscrew_filter_merge.scad]
2025-08-31 feat: Improve documentation and fix OpenSCAD scripts
    This commit includes several improvements and bug fixes based on user feedback:
    `BOM.md` and `TODO.md` files to keep the documentation atomic.
    corrected.
    - The control variables in `corkscrew_f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
    [corkscrew_filter_merge.scad]
2025-09-02 feat: Improve documentation and fix multiple OpenSCAD bugs
    This commit includes several improvements and bug fixes based on user feedback throughout the session.
    - Multiple bugs in `corkscrew_filter_merge.scad` have been fixed:
    1. A syntax error in the `for` loops was corrected (changed from
    C-style to OpenSCAD syntax).
    2. A logical bug in the `HexArrayLayout` module's vector
    calculation was fixed, allowing the hexagonal array to be
    generated correctly.
    3. The control variables (`US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
    [corkscrew_filter_merge.scad]
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2025-09-04 refactor: Organize OpenSCAD files into modules
    Breaks down the monolithic corkscrew_filter_v40.scad into a more manageable, modular structure.
    Separates configuration, modules, and the main entry point into distinct files:
    - config.scad: User-configurable parameters.
    - modules/: Directory for all geometric and utility modules.
    - corkscrew.scad: Main file with includes and top-level logic.
    Replaces the existing barb implementation with a corrected version from BarbGenerator-v3.scad.
    Adds a new feature: debris exit channels for the hex array filter, controlled by the ADD_DEBRIS_EXIT_CHANNELS flag.
    [assemblies.scad, config.scad, core.scad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]
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2025-11-05 updated teh barbed coupling and the corkscrew filter
    the corkscrew filter had the wrong file input for the config file, but it appears to work now
    the v22 is a work in progress
    new fittings for the venturi and gravity fed sand blasters are in the repo now.
    [barb_coupling.stl, barb_coupling_sandblaster.scad, barb_coupling_sandblaster.stl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]
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2025-11-19 adjusted parameters, fixed the dovetail o ring generator, the one and three files look good, the 21 needs more work
    [One_Corkscrew_param.scad, Three_Corkscrews_param.scad, TwentyOne_Corkscrews_param.scad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]
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2026-01-27 Refactor legacy files, add Filter Holder, and parameterize couplings
    - Implemented `modules/filter_holder.scad` utilizing BOSL2 for threading and the new Barb module. Fixed threading geometry to prevent overlap with smooth walls.
    - Implemented `modules/custom_couplings.scad` to support legacy coupling geometries.
    - Updated `config.scad` and `corkscrew.scad` to support new parts.
    - Added `.gitmodules` for BOSL2 dependency.
    - Updated `TODO.md` with documentation and tracking.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
    [BarbGenerator-v3.scad, ThirstyCorkscrew.scad, ThirstyCorkscrew_3Bin_Scaled.scad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]
2026-01-27 Refactor legacy files, add Filter Holder, and parameterize couplings
    - Updated `TODO.md` with documentation and tracking.
    - Ensured `corkscrewFilter` direct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
    [config_coupling_cartridge.scad, config_coupling_sandblaster.scad]
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2026-01-28 Fix incorrect relative include paths in module files
    Updated `modules/inlets.scad`, `modules/custom_couplings.scad`, and `modules/filter_holder.scad` to use relative paths for including sibling files within the `modules/` directory. This resolves OpenSCAD compilation warnings where `include <modules/...>` failed to locate files when called from within the `modules/` directory.
    [custom_couplings.scad, filter_holder.scad, inlets.scad]
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2026-01-29 Fix barb direction, gap under shoulder, and corkscrew intersection diameter
    - Reversed the taper direction in `modules/barbs.scad` so barbs ramp correctly for hose insertion and retention.
    - Adjusted Z-position of `BarbInlet` in `modules/assemblies.scad` to sit flush in the spacer recess, eliminating the gap.
    - Added XY alignment logic for `BarbInlet` and its recess in `modules/assemblies.scad`. The inlet is now offset to match the helical channel's position at the interface, fixing the effective diameter constriction.
    - Fixed an OpenSCAD scoping bug where recess variables were not accessible outside their initialization block.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
    [assemblies.scad, barbs.scad]
2026-01-29 Refactor BarbInlet alignment to use rotation for precise mesh matching
    - Replaced manual XY offset calculation with `rotate(ra) translate([R, 0, z])` in `modules/assemblies.scad`. This ensures that the BarbInlet mesh rotation aligns perfectly with the Helical Void mesh, eliminating "stair stepping" artifacts.
    - Applied the same rotation logic to the Recess Cutter to ensure the hole in the spacer matches the inlet geometry exactly.
    - Preserved Z-position fixes for the "gap" issue (Inlet seated flush in recess).
    - Preserved Barb geometry fix (swapped d1/d2 for correct retention).
    [assemblies.scad]
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2026-01-31 Refactor FilterHolder to use Face Seals and correct thread placement
    When `thread_outer` or `thread_inner` is enabled in `FilterHolder`:
    1. Swaps thread position to the proximal segment (base) to allow proper engagement with mating parts (e.g., pipe rim).
    2. Implements Axial (Face) Seals instead of Radial Seals.
    - For Outer connection: Face groove on the underside of the Base Plate Flange.
    - For Inner connection: Face groove on the underside of the Base Plate (inside the hole).
    3. Updates `base_plate_od` calculation to ensure a proper flange overlapping the pipe wall, using the new `tube_wall` parameter passed from `corkscrew.scad`.
    4. Adds `tube_wall` parameter to `FilterHolder` modul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
    [corkscrew.scad, filter_holder.scad]
2026-01-31 Fix FilterHolder geometry when using outer threads
    Modified `modules/filter_holder.scad` to correctly preserve the inner cup structure when `thread_outer=true`.
    Previously, the code subtracted a solid cylinder to hollow out the threaded rod, which inadvertently deleted the inner lip (cup) geometry.
    The fix replaces this with a conditional annulus (tube) subtraction that removes material only between the outer wall and the inner cup, ensuring both structures remain intact. This resolves the issue of missing walls and floating O-ring visualizers.
    [filter_holder.scad]
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2026-02-02 Refine CorkscrewSlitKnife with polyhedral ramp geometry
    - Replaced simple linear extrusion in `CorkscrewSlitKnife` with a new `RampedKnifeShape` module.
    - `RampedKnifeShape` features a 0.5mm chamfered leading edge to improve separation efficiency.
    - Implemented chamfer using `polyhedron()` to create a loft from a scaled-down base to a full-size profile, avoiding WASM memory limits encountered with `hull()`.
    - Main body uses `linear_extrude` with pre-shifted polygon points to avoid `translate()` inside extrusion, ensuring compatibility with the WASM environment.
    - Verified visual geometry via `flat_end_screw.stl` generation.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
    [cutters.scad, test_knife.stl]
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2026-02-02 Fix FilterHolder O-ring visualization and reinforce central bore
    - Modified `modules/filter_holder.scad` to use Face Seal visualization when `thread_outer` is true, resolving a "wavy" O-ring artifact on external threads.
    - Extended the central bore subtraction cylinder in `FilterHolder` to ensure a continuous airflow path through the barb and base plate.
    - Verified fix by generating PNGs and confirming clear bore and correct seal placement.
    [filter_holder.scad]
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2026-02-03 Fix timeout in CFD volume generation and ignore STL files
    - Update .gitignore to exclude *.stl files
    - Add HollowHelicalShape module for efficient hollow screw generation
    - Refactor ModularFilterAssembly to use HollowHelicalShape, reducing screw generation time from minutes to seconds
    - Note: HelicalOuterSupport remains computationally expensive (~6m) but total generation time is now closer to limits.
    [core.scad]
2026-02-03 Optimize ModularFilterAssembly geometry generation
    - Use `HollowHelicalShape` for bins to avoid global boolean difference.
    - Remove `MasterVoidHelix` subtraction from the entire assembly.
    - Spacers retain `MasterSolidHelix` subtraction to ensure flow path continuity.
    [assemblies.scad]
2026-02-03 Fix export timeouts for ModularFilterAssembly CFD volumes
    Refactored `ModularFilterAssembly` to avoid O(N^2) complexity by using local hollow helix segments instead of a global intersection.
    Optimized `HelicalOuterSupport` to reduce vertex count by capping resolution and slice count.
    Disabled `HelicalOuterSupport` generation when `GENERATE_CFD_VOLUME` is enabled to prevent CSG explosion.
    Capped global `high_res_fn` to 60 in `config.scad` to ensure stability in the WASM environment.
    These changes reduce render time for complex geometries from >400s (timeout) to ~320s.
    [assemblies.scad, config.scad, helpers.scad]
2026-02-03 Fix ModularFilterAssembly phase alignment
    Corrects the rotational phase alignment between screw segments, spacer holes, and helical supports in `ModularFilterAssembly`.
    - Offsets `HollowHelicalShape` rotation by `-local_twist / 2` to account for `linear_extrude(center=true)` phase shift.
    - Offsets `HelicalShape` (spacer cutter) rotation by `-cut_twist / 2` for the same reason.
    - Advances `HelicalOuterSupport` rotation by `twist_rate * spacer_height_mm / 2` to align its base phase with the top of the spacer.
    [assemblies.scad]
2026-02-03 Optimize ModularFilterAssembly and fix config.scad variable shadowing
    - Optimization: Refactored `ModularFilterAssembly` to use `MasterHollowHelix` (via `HollowHelicalShape`) instead of a global boolean subtraction of a void helix. This reduces CSG complexity and prevents timeouts (~5x speedup).
    - Config Fix: Resolved an issue where `config.scad` was overwriting `part_to_generate` with the default value even when set by the includer, due to OpenSCAD variable scoping rules. Introduced `default_part_to_generate` in `config.scad` and moved fallback logic to `corkscrew.scad`.
    - Verified correctness via regression tests and manual visualization.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
    [assemblies.scad, config.scad, corkscrew.scad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]
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2026-02-04 Resolve merge conflicts and optimize ModularFilterAssembly
    - Resolved conflict in `modules/assemblies.scad`.
    - Re-applied `MasterHollowHelix` optimization to prevent timeouts.
    - Preserved `default_part_to_generate` fix in `config.scad`.
    [assemblies.scad, config.scad, helpers.scad]
2026-02-04 Resolve conflicts and enforce modular filter optimization
    - Merged origin/main.
    - Confirmed `modules/assemblies.scad` uses `MasterHollowHelix` logic.
    - Confirmed `config.scad` uses `default_part_to_generate`.
    [config.scad, corkscrew.scad, filter_holder.scad]
2026-02-04 Fix OpenSCAD variable recursion error in high_res_fn logic
    Refactors the `high_res_fn` assignment in `config.scad` to use intermediate variables (`_requested_high_res_fn`, `_actual_high_res_fn`). This prevents a self-referential assignment (`high_res_fn = min(high_res_fn, 60)`) which caused OpenSCAD to crash with a "min() parameter could not be converted" error (and return code 1) during the optimization loop. The fix correctly handles both default values and command-line overrides (`-D`) while enforcing the 60-step cap required for stability in the WASM environment.
    [config.scad]
2026-02-04 Fix duplicate screw segment geometry in ModularFilterAssembly
    Removes a redundant and incorrectly nested `MasterHollowHelix` intersection block in `modules/assemblies.scad`. This legacy code block caused screw segments to be generated twice (once via the legacy intersection method and once via the optimized `HollowHelicalShape` method), leading to "Volumes: 2" issues and potential geometry misalignment. The removal ensures only the optimized local segment generation is used.
    [assemblies.scad]
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2026-02-04 Fix missing cartridge holder geometry and add customization parameters
    - Added `filter_holder_cartridge_wall_height` and `filter_holder_cartridge_offset` to `config.scad` and `FilterHolder` module.
    - Refactored `FilterHolder` geometry to explicitly generate the Cartridge Holder (Socket/Nipple) ensuring it exists even when Plug is modified.
    - Switched to explicit `anchor=BOTTOM` for cylinder/threaded_rod generation to fix positioning ambiguities.
    - Fixed logic for Plug cleanup subtraction to preserve the Cartridge Holder.
    [config.scad, filter_holder.scad]
2026-02-04 Fix FilterHolder geometry: add distal face seal and hollow socket
    - Add logic to subtract a smooth socket cylinder in `FilterHolder` when no threads are present, fixing the "purple circle" issue where the socket was solid.
    - Add a distal face seal groove and O-ring visualization to the threaded plug configuration (`tube_thread_outer=true`), addressing the request for a recessed O-ring at the "green circled part".
    - Ensure the new geometry operations are correctly scoped within the `tube_thread_outer` conditional block.
    - Verify changes with a reproduction script and `export.js`.
    [filter_holder.scad]
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2026-02-05 Fix ModularFilterAssembly inlet alignment
    This commit updates `modules/assemblies.scad` to ensure that "threaded" and "pressfit" inlets are correctly aligned with the helical channel of the `ModularFilterAssembly`.
    Previously, these inlet types were centered at `[0,0]`, causing misalignment with the helical channel which is offset by `helix_path_radius_mm`. The fix unifies the placement logic to use the same offset and rotation calculations as the "barb" inlet, ensuring proper flow connection.
    It also updates the recess cutter logic to match the new inlet positions.
    [assemblies.scad]
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2026-02-05 Fix misalignment in ModularFilterAssembly using Master Helix method
    - Reverted the optimized "local segment" generation method in `modules/assemblies.scad` to the robust "Master Helix" intersection method.
    - Updated screw segment generation to intersect `MasterHollowHelix` with the segment cylinder.
    - Updated spacer hole generation to subtract `MasterSolidHelix` from the spacer body.
    - This ensures all helical components are derived from a single, continuous mathematical definition, preventing phase shifts and misalignments between segments and spacers.
    - Verified generation using `export.js` with `part_to_generate=modular_filter_assembly`.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
    [assemblies.scad]
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
